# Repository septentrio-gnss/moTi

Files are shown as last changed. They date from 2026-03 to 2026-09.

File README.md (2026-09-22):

# moTi
| Role | Contact |
|---|---|
| Author | [laekaz](https://github.com/laekaz) |
| Maintainer  | [Septentrio GNSS GitHub User](githubuser@septentrio.com) |
| License | [OCP CLA](https://www.opencompute.org/documents/ocp-cla) |
| Project | [Stargate](https://stargate-receiver.com/) |

<p align="center">
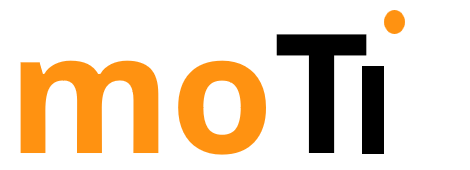
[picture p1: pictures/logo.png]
  
</p>

This project is co-funded by the European Union Agency for the Space Programme under the Fundamental Elements Grant EUSPA/GRANT/02/2024

## Table of Contents
* [Introduction](#introduction)
* [What is a moTi?](#what-is-the-moTi)
  * [Can I buy it?](#can-i-buy-it)
* [What is a Time Card?](#what-is-a-time-card)
* [What is a Mosaic-G5 T?](#what-is-a-mosaic-g5-t)
* [Who is Septentrio?](#who-is-septentrio)
  * [Why open-source?](#why-open-source)
* [Disclaimer](#disclaimer)
* [Deliverables](#deliverables)
  * [M.2 Form Factor](#m2-form-factor)
* [User Documentation](#user-documentation)
  * [System Setup](#system-setup)
    * [Boot Linux](#boot-linux)
    * [Check the GNSS Status (Satellite Time)](#check-the-gnss-status-satellite-time)
    * [Output the PPS and Clock](#output-the-pps-and-clock)
    * [Use the PHC from Linux](#use-the-phc-from-linux)
    * [When the Card is Installed and Running](#when-the-card-is-installed-and-running)
    * [If Something Goes Wrong](#if-something-goes-wrong)
* [Design Documentation](#design-documentation)
  * [Ordering Mosaic](#ordering-mosaic)
  * [Board Connections and Indicators](#board-connections-and-indicators)
    * [Pinout for M.2 Key B Connector](#pinout-for-m2-key-b-connector)
    * [USB 2.0](#usb-20)
    * [UART](#uart)
    * [PPS Out](#pps-out)
    * [Event 1 (PPS IN)](#event-1-pps-in)
    * [LED D1](#led-d1)
    * [Antenna Connector](#antenna-connector)
## Introduction 
## What is a moTi?

<p align="center">
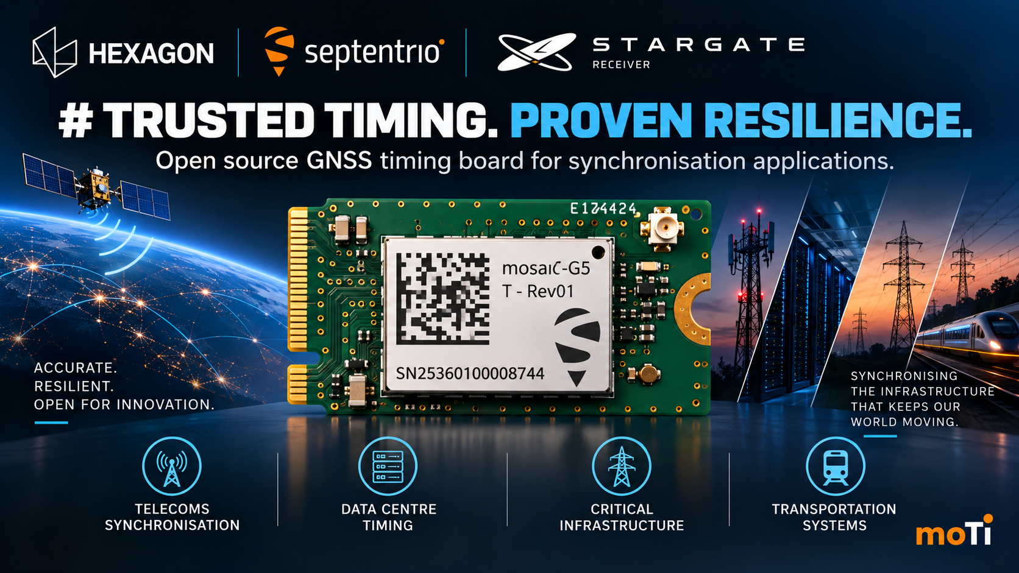
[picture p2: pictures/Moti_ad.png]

</p>

moTi is a timing module that provides accurate and reliable synchronisation signals for time-sensitive systems. It is based on a standardised M.2 form factor that can be easily integrated into compatible carrier boards such as the Open Compute Project (OCP) [Time Card](#what-is-a-Time-Card?).
This board receives precise timing information from Septentrio’s mosaic-G5 T GNSS (Global Navigation Satellite System) module. It then generates synchronisation outputs such as Pulse Per Second (PPS) and Time of Day (ToD) data. These signals are then used to synchronise services, in network interface cards (NICs), and other hardware in data centres and communication systems.

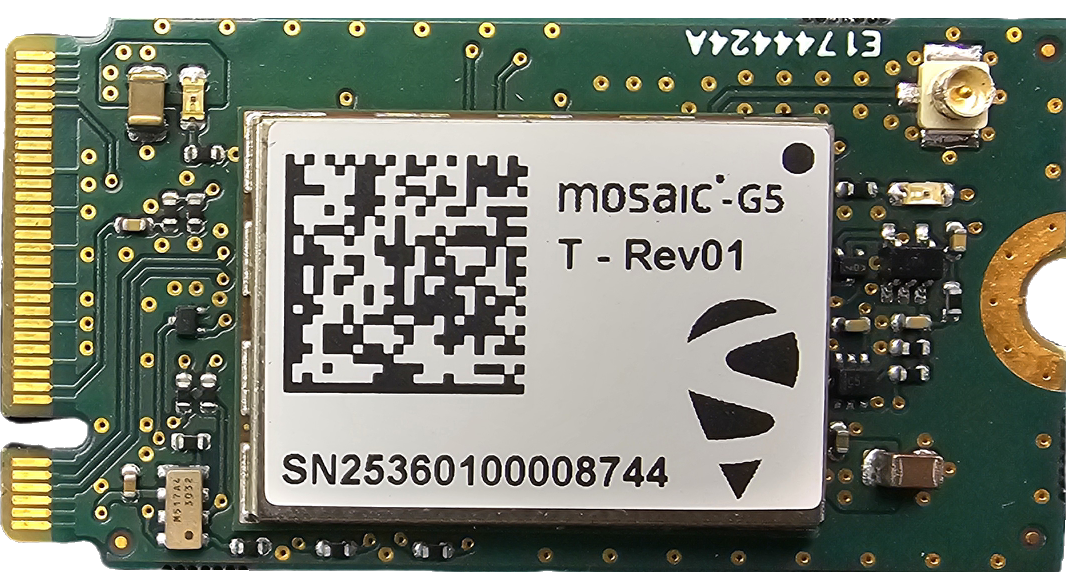
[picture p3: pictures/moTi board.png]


## What is a Time Card?
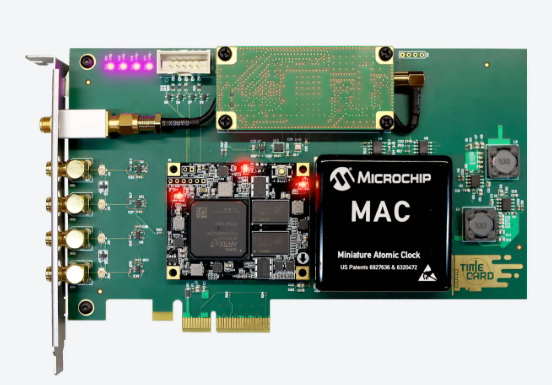
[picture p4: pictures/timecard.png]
card


A Time Card is a PCIe card that is designed to plug into a server and provides precision time outputs such as PPS (Pulse Per Second) and ToD (Time of Day). It provides this precise timing to the server’s clock and network hardware, enabling high-accuracy synchronisation using protocols like the NTP or PTP. moTi connects to the Time Card as a timing source, supplying the card with GNSS time signals in standardised form factor.

Originally, it was developed by Meta and released through the Open Compute Project

More information about the Time Card on this [link](https://fr.scribd.com/document/803083407/M-2-Sync-Module-OCP-Base-Specification-1-1-1) or [Github](https://github.com/Time-Appliances-Project/Time-Card?tab=readme-ov-file) 

## What is a mosaic-G5 T?
[Septentrio mosaic-G5 T](https://www.septentrio.com/en/products/gnss-receivers/gnss-receiver-modules/mosaic-g5-t) is a compact, low-power GNSS timing receiver module with multi-band, multi-frequency capability. Designed for critical infrastructure and other applications where resilient and precise timing is essential, it ensures maximum security and uptime. It tracks all Global Navigation Satellite System (GNSS) constellations and supports both current and future signals. 

## Who is Septentrio?
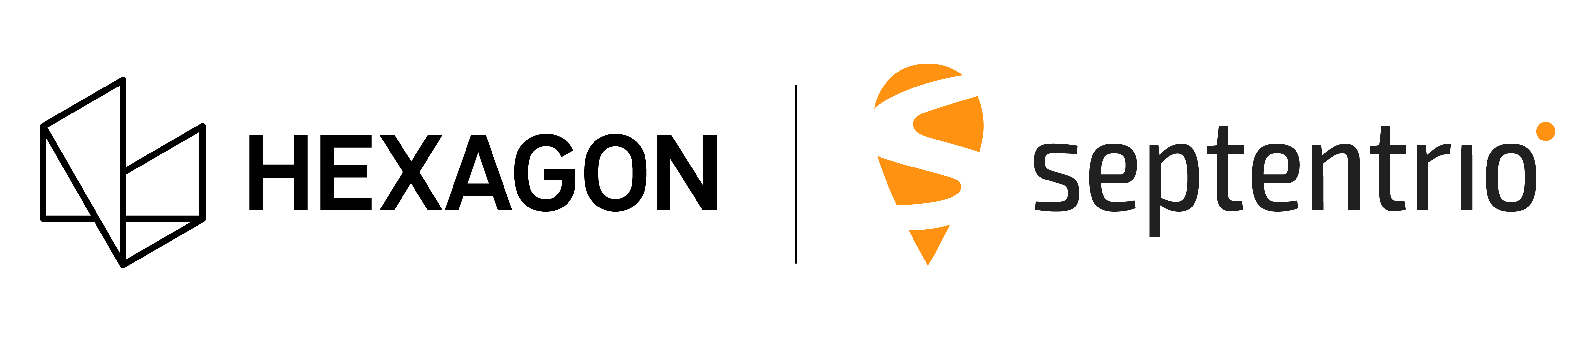
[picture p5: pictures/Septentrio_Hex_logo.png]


Septentrio is a leading company that designs, manufactures and sells high precision and multi-frequency GPS/GNSS receivers for demanding applications. Septentrio products are used in different industries including automotive, marine, construction, rail, machine control, logistics, precision agriculture, geographic information systems (GIS), Unmanned Aerial Vehicles (UAVs), surveying, mapping and scientific development. Septentrio’s receivers constantly deliver accurate and precise GNSS positioning scalable to centimetre-level and designed to perform perfectly in challenging environments. 

Septentrio's technology offers high accuracy and reliability thanks to GNSS + algorithms as well as [Advanced interference Monitoring and Mitigation (AIM+)](https://www.septentrio.com/en/learn-more/advanced-positioning-technology/aim-anti-jamming-protection) This protects your application against jamming (RF interference) and spoofing (malicious attacks).

For more information about Septentrio products go to [**https://www.septentrio.com/**](https://web.septentrio.com/GH-SSN-home).

### Why open-source?
This board is open source to encourage collaboration, customization, and innovation. By making the design files publicly available, developers and engineers can study, modify, and adapt the hardware to fit their specific applications, reducing development time and cost. It also promotes transparency and avoids vendor lock-in, allowing users to fully understand and control the design.

## Disclaimer
This project is offered as-is. The main interfaces have been tested, but the design has not been fully checked or approved by the author or Septentrio. You are responsible for how you use it in your own projects. For guidance on working with Septentrio’s GNSS mosaic modules, we suggest reaching out to Septentrio directly.

Support website: https://www.septentrio.com/en/support

### Deliverables
This open-source project contains the following files for designers, producers and integrators around Septentrio's mosaic modules.
|Files |description |
|---|---|
|[moTi.kicad_pro](./KiCad_Files/KiCad/moTi/moTi.kicad_pro)| KiCAD project|
|[moTi.kicad_sch](./KiCad_Files/KiCad/moTi/moTi.kicad_sch)|KiCAD schematic|
|[mosaic-G5.kicad_sch](./KiCad_Files/KiCad/moTi/mosaic-G5.kicad_sch)|KiCAD mosaic-G5 schematic sheet |
|[M2_Edge connector.kicad_sch](./KiCad_Files/KiCad/moTi/M2_Edge%20connector.kicad_sch)|KiCAD M.2 Key B schematic sheet|
|[Clockdetect.kicad_sch](./KiCad_Files/KiCad/moTi/Clockdetect.kicad_sch)|KiCAD clock schematic sheet|
|[moTi.kicad_pcb](./KiCad_Files/KiCad/moTi/moTi.kicad_pcb)|KiCAD PCB layout|
|[moTi_Schematics.pdf](moTi_Schematics.pdf)|schematic PDF|

#### M.2 form factor

The M.2 form factor provides a compact interface for expansion cards.The moTi board is M.2 Key B connector, but it can also fit into some Key M or B+M slots. B+M slots are designed with extra notches so they accept both Key B and Key M modules, allowing flexibility in installation. This means your Key B board can interconnect with a Key M-compatible slot as long as it’s a B+M slot, ensuring proper electrical connections and compatibility.

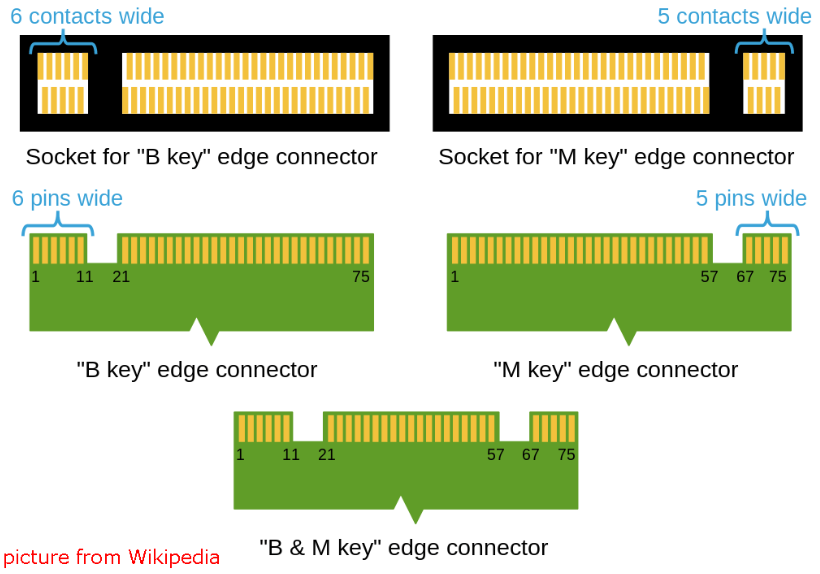
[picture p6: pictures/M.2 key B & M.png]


## User documentation

### System Setup

Before you physically install anything: 
* Make sure you have a free PCIe slot
* Make sure your BIOS supports Virtualization/IOMMU for Linux use
* You must connect the GNSS antenna to its SMA connector before inserting the Time Card.
##### Boot Linux 
Boot Linux with the Time Card inserted. 

If your Linux system uses the Kernel 5.15 or newer the Time Card driver is already included. So the kernel loads the driver automatically.

The devices are exposed by the driver like:

`/dev/ptpX` -> PHC device 

`/dev/ppsY` -> PPS pulse signal

`/sys/class/timecard/ocp0/`-> status and attributes

These are the time interface paths in the OS.

Command example to see the devices:
```
ls -l /sys/class/timecard/ocp0/
```

This will show many devices including GNSS, PPS, PHC clock and atomic clock serial
##### Check the GNSS status (satellite time)
Once Linux has detected the Time Card:

* GNSS time is usually on a serial port like `/dev/ttyS7` or similar.
* You can run `gpsd` or a tool like `cgps` to check the satellite status.

For example:

```
gpsd /dev/ttyS5
```

* To make sure GPS is sending messages, use tio

```
tio -b 115200 /dev/ttyS5
```
* Check if the FPGA time is correct by checking the NMEA

```
tio -b 115200 /dev/ttyS0
```

##### Output the PPS and Clock
available_sma_outputs contains all available outputs

To list available outputs:
```
cat available_sma_outputs
    10MHz PHC MAC GNSS1 GNSS2 IRIG DCF GEN1 GEN2 GEN3 GEN4 GND VCC
```
```
 cat /sys/class/timecard/ocp0/available_sma_outputs 
```
Output on SMA:
* FPGA PPS 
```
echo OUT: PHC >> sma1
```
* Atomic Clock PPS
```
echo OUT: MAC >> sma1
 ```
* GPS Module's PPS 
```
echo OUT: GNSS1 >> sma1
```

##### Use the PHC from Linux
The PHC (Precision Hardware Clock) device exposed by the driver can be used to sync the Linux system clock

##### When the card is installed and running
Once everything is configured:
* The Time Card provides accurate time to Linux
* You can serve time to network clients using NTP or PTP
* Your system becomes a Stratum 1 time source 

This means your server can act as a time source for the whole infrastructure.

##### If something goes wrong
* If the driver fails to load: make sure you have a newer Linux kernel
* If /dev/ptp doesn’t show: check BIOS PCIe settings
* If no GNSS: verify if antenna is connected.

These are normal steps to get the Time Card recognized by Linux.

## Design documentation
#### Ordering mosaic
For orders of the mosaic-G5 T, please contact [Septentrio](https://www.septentrio.com/en/products/gnss-receivers/gnss-receiver-modules/mosaic-g5-t)

### Block diagram
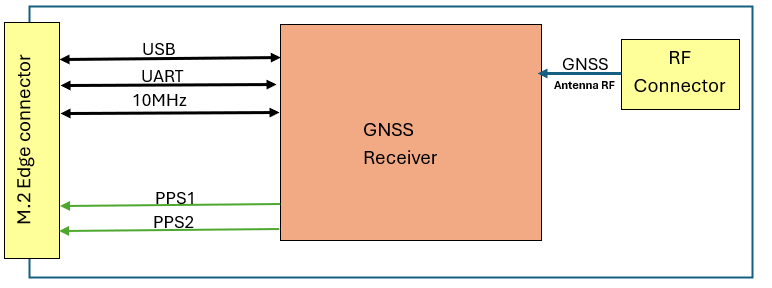
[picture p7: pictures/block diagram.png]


The above block diagram is showing the overview communication between the antenna, receiver and M.2 edge connector. 

### Board connections and indicators

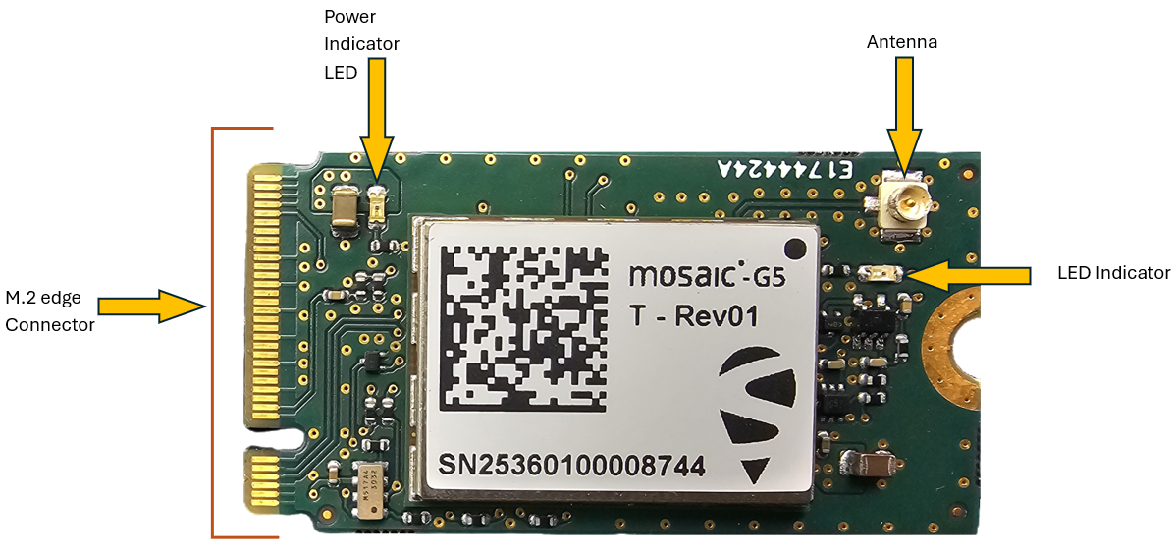
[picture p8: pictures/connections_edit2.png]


| interface signals |I/O Type | Voltage | Signal Description |
|---|---|---|---|
| Power | Power |  3.3V |3.3 V Supply pin. |
| UART | I&O | 3.3V | Universal Asynchronous Receiver Transmitter, RX & TX|
|USB | I/O |  3.3V | Universal Serial Bus interface, USB D+ and D− differential data lines|
| PPS Out 1 | O | 3.3V |Pulse Per Second signal out#1.
| PPS Out 2 | O | 3.3V |Pulse Per Second signal out#2.
| Event 1 (PPS IN)  | I | 3.3V  |Pulse Per Second reference signal input. If not used, connect to ground on Platforms.|
| CLK_IN | I | 3.3V |10MHz reference clock input. If not used, connect to ground|
| CLK_OUT | O | 3.3V |10MHz output clock. |
| LED D1 | O | 3.3V |Power Supply indicator|

#### Pinout for M.2 Key B Connector

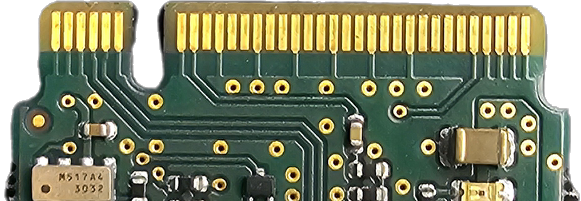
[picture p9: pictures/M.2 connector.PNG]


| Pin # |Signal |
|---|---|
| 7	 |USB D+ |
| 9	 |USB D- |
| 23	|10MHz clock input |
| 67	|nRST_IN |
| 2, 4	|VBAT |
| 10	|LED#1 |
| 20	|PPS2 output |
| 22	|Ref_CLK_SEL |
| 24	|PPS input |
| 46	|PPS1 output |
| 48	|10MHz clock output|
| 62	|UART COM1 Rx |
| 64	|UART COM1 Tx |
| 70, 72, 74| Power 3.3V |
| GND	|GND |

**USB 2.0** pins USB_D+ and USB_D- 
When the module is inserted into a card that supports USB pins on its edge connector, the USB interface works just like it would on any other device. It is used for data, configuration, and control. It carries data such as , Time of Day (ToD) for the GNSS, diagnostic messages and firmware update channels. The Time Card will act as the USB host.

**UART** (Universal Asynchronous Receiver Transmitter)
This is a standard serial port using TX and RX pins.

**PPS Out** timing reference signal output. This supplies high-precision timing references directly into the Time Card clocking system. 

**Event 1 (PPS IN)** This pin detects a pulse from an external device and records the exact GNSS time when the pulse happened. It is connected to the eventB pin of the mosaic-G5 T

##### LED D1
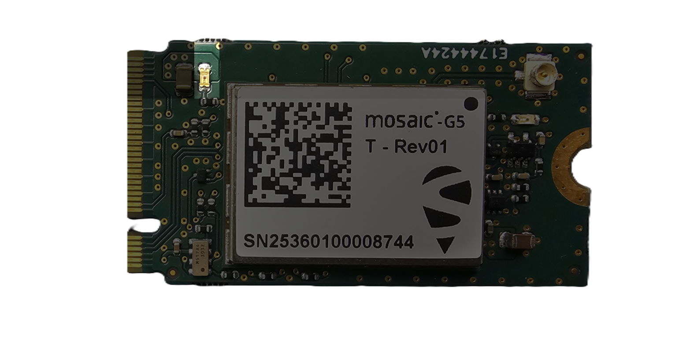
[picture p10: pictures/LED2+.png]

This LED indicates whether the Module is ON/OFF

##### Antenna connector
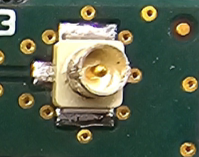
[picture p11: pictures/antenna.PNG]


The board provides a U.FL (UMCC) 50 Ω PCB receptacle for connecting an external GNSS antenna.
This miniature RF connector is commonly used in compact embedded and wireless systems due to its small size and reliable high-frequency performance.

**Connector Details**
* Type: U.FL (UMCC) Receptacle
* Impedance: 50 Ω
* Application: External active/passive GNSS antenna connection

**Notes**
* Use a compatible U.FL/IPX coaxial cable assembly when connecting an antenna.
* Keep RF cable lengths as short as possible to minimize signal loss.
* Ensure the antenna system is properly matched to 50 Ω impedance for optimal RF performance.

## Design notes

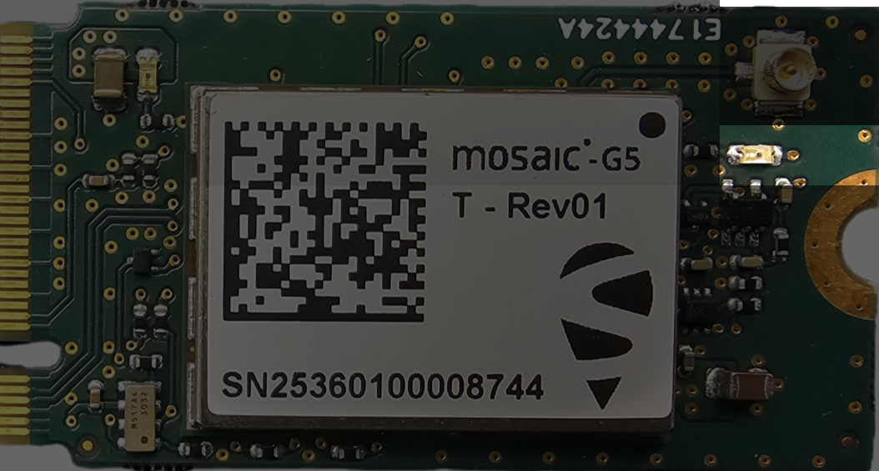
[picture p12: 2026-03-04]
pictures/LED1.PNG

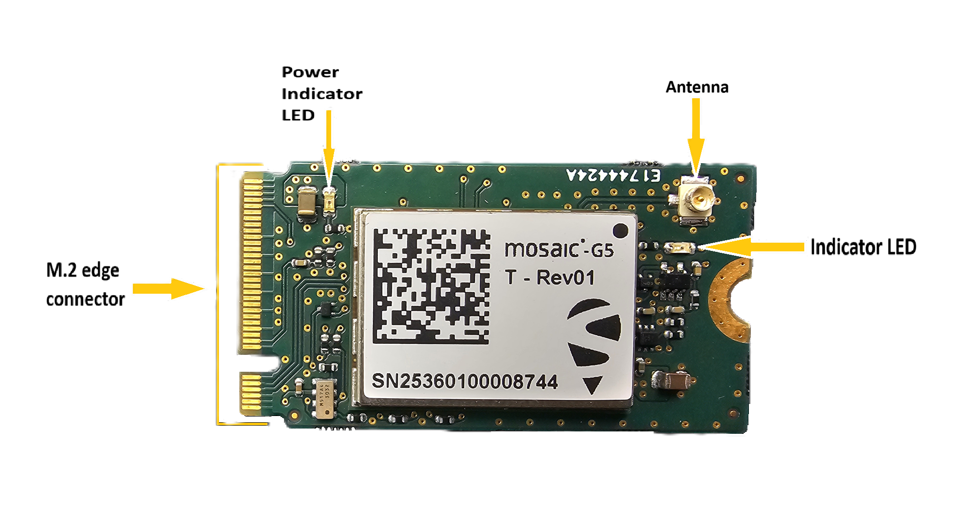
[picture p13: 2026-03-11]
pictures/connections_edit.png

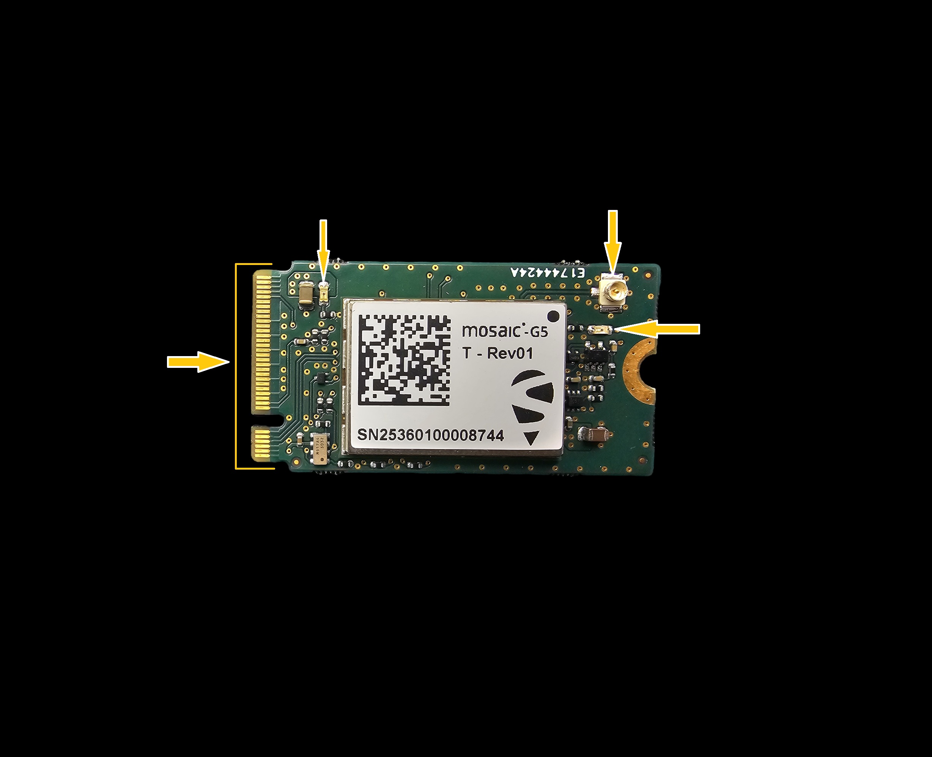
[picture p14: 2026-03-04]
pictures/detailed.jpg

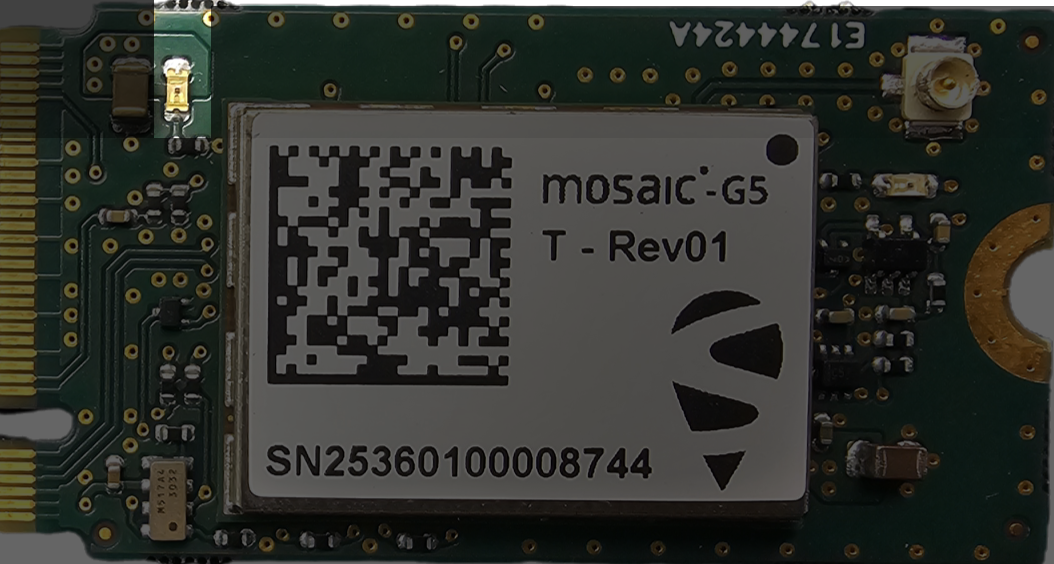
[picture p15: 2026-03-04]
pictures/LED2 .PNG

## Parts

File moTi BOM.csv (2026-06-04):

Reference | Value | Description | Qty | Manufacturer_Name | Manufacturer_Part_Number
C1 | 22u | Unpolarized capacitor | 1 | Murata Electronics | GRM21BC81C226ME44L
C2 | 100n | Unpolarized capacitor | 1 | YAGEO | CC0402KRX7R7BB104
C3 | 47u | CAP CER 47UF 10V X5R 0805 | 1 | Murata Electronics | GRM21BR61A476ME15L
C8 | 1.0n | Unpolarized capacitor | 1 | YAGEO | CC0402KRX7R9BB102
C9 | 1.0n | Unpolarized capacitor | 1 | YAGEO | CC0402KRX7R9BB102
D1 | LED | Light emitting diode | 1 | LITEON | LTST-C191KGKT
D2 | LED | Light emitting diode | 1 | LITEON | LTST-C191KGKT
J1 | U.FL-R-SMT_10_ | U.FL (UMCC) Connector Receptacle, Male Pin 50 Ohms Surface Mount Solder | 1 | Hirose | U.FL-R-SMT(10)
Q1 | NTK3139PT5G | P-channel Switch with Low RDS(on); 44% Smaller Footprint and 38% Thinner than SC-89; Low Threshold Levels, 1.5 V RDS(on) Rating; RoHS Compliant; Operated at Low Logic Level Gate Drive | 1 | onsemi | NTK3139PT5G
Q2 | NTK3043NT1G | Enables High Density PCB Manufacturing; 44% Smaller Footprint than SC-89 and 38% Thinner than SC-89; Low Voltage Drive Makes this Device Ideal for Portable Equipment; Low Threshold Levels, VGS(TH) < 1.3 V; Low Profile (< 0.5 mm) Allows It to Fit Easily in Extremely Thin Environments such as Protable Electronics.; Operated at Standard Logic Level Gate Drive, Facilitating Future Migration to Lower Levels Using the Same Basic Topolgy. | 1 | onsemi | NTK3043NT1G
R1 | 1.0k | Resistor | 1 | Vishay | CRCW04021K00FKEDC
R10 | 10k | Resistor | 1 | Vishay | CRCW040210K0FKED
R11 | 10k | Resistor | 1 | Vishay | CRCW040210K0FKED
R2 | 1.5k | Resistor | 1 | Vishay | CRCW04022K20FKED
R3 | 1.0k | Resistor | 1 | Vishay | CRCW04021K00FKEDC
R4 | 1.0k | Resistor | 1 | Vishay | CRCW04021K00FKEDC
R7 | 10k | Resistor | 1 | Vishay | CRCW040210K0FKED
R8 | 4k7 | Resistor | 1 | Vishay | CRCW04024K70FKED
R9 | 10k | Resistor | 1 | Vishay | CRCW040210K0FKED
U1 | mosaic-G5 T | GNSS timing receiver | 1 | Septentrio | 410504
U2 | TLV3511DCKR | Comparator General Purpose Push-Pull, Rail-to-Rail SC-70-5 ,2.7V ~ 5.5V ,85mA @ 5V ,2.3mV ,-40C ~ 125C ,SC-70-5 | 1 | Texas Instruments | TLV3511DCKR
U5 | SN74LVC1G3157DRLR | Single-Pole, Double-Throw Analog Switch | 1 | Texas Instruments | SN74LVC1G3157DRLR

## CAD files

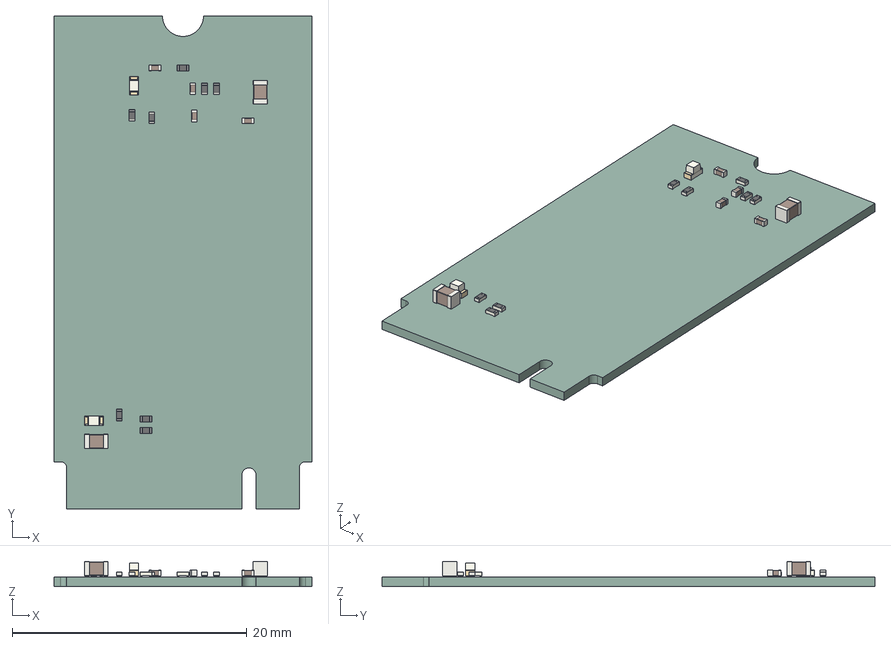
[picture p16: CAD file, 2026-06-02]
KiCad_Files/CAD/moTi.step
22.0 x 42.0 x 2.16 mm
R_0402_1005Metric x 8
C_0402_1005Metric x 4
LED_0603_1608Metric x 2
C_0805_2012Metric x 2
moTi_PCB

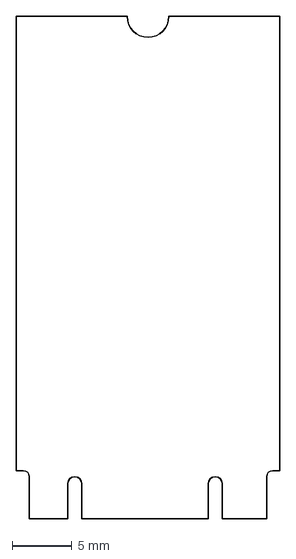
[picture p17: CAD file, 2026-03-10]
KiCad_Files/KiCad/moTi_PCB_OUTLINE.dxf
22.0 x 42.0 mm

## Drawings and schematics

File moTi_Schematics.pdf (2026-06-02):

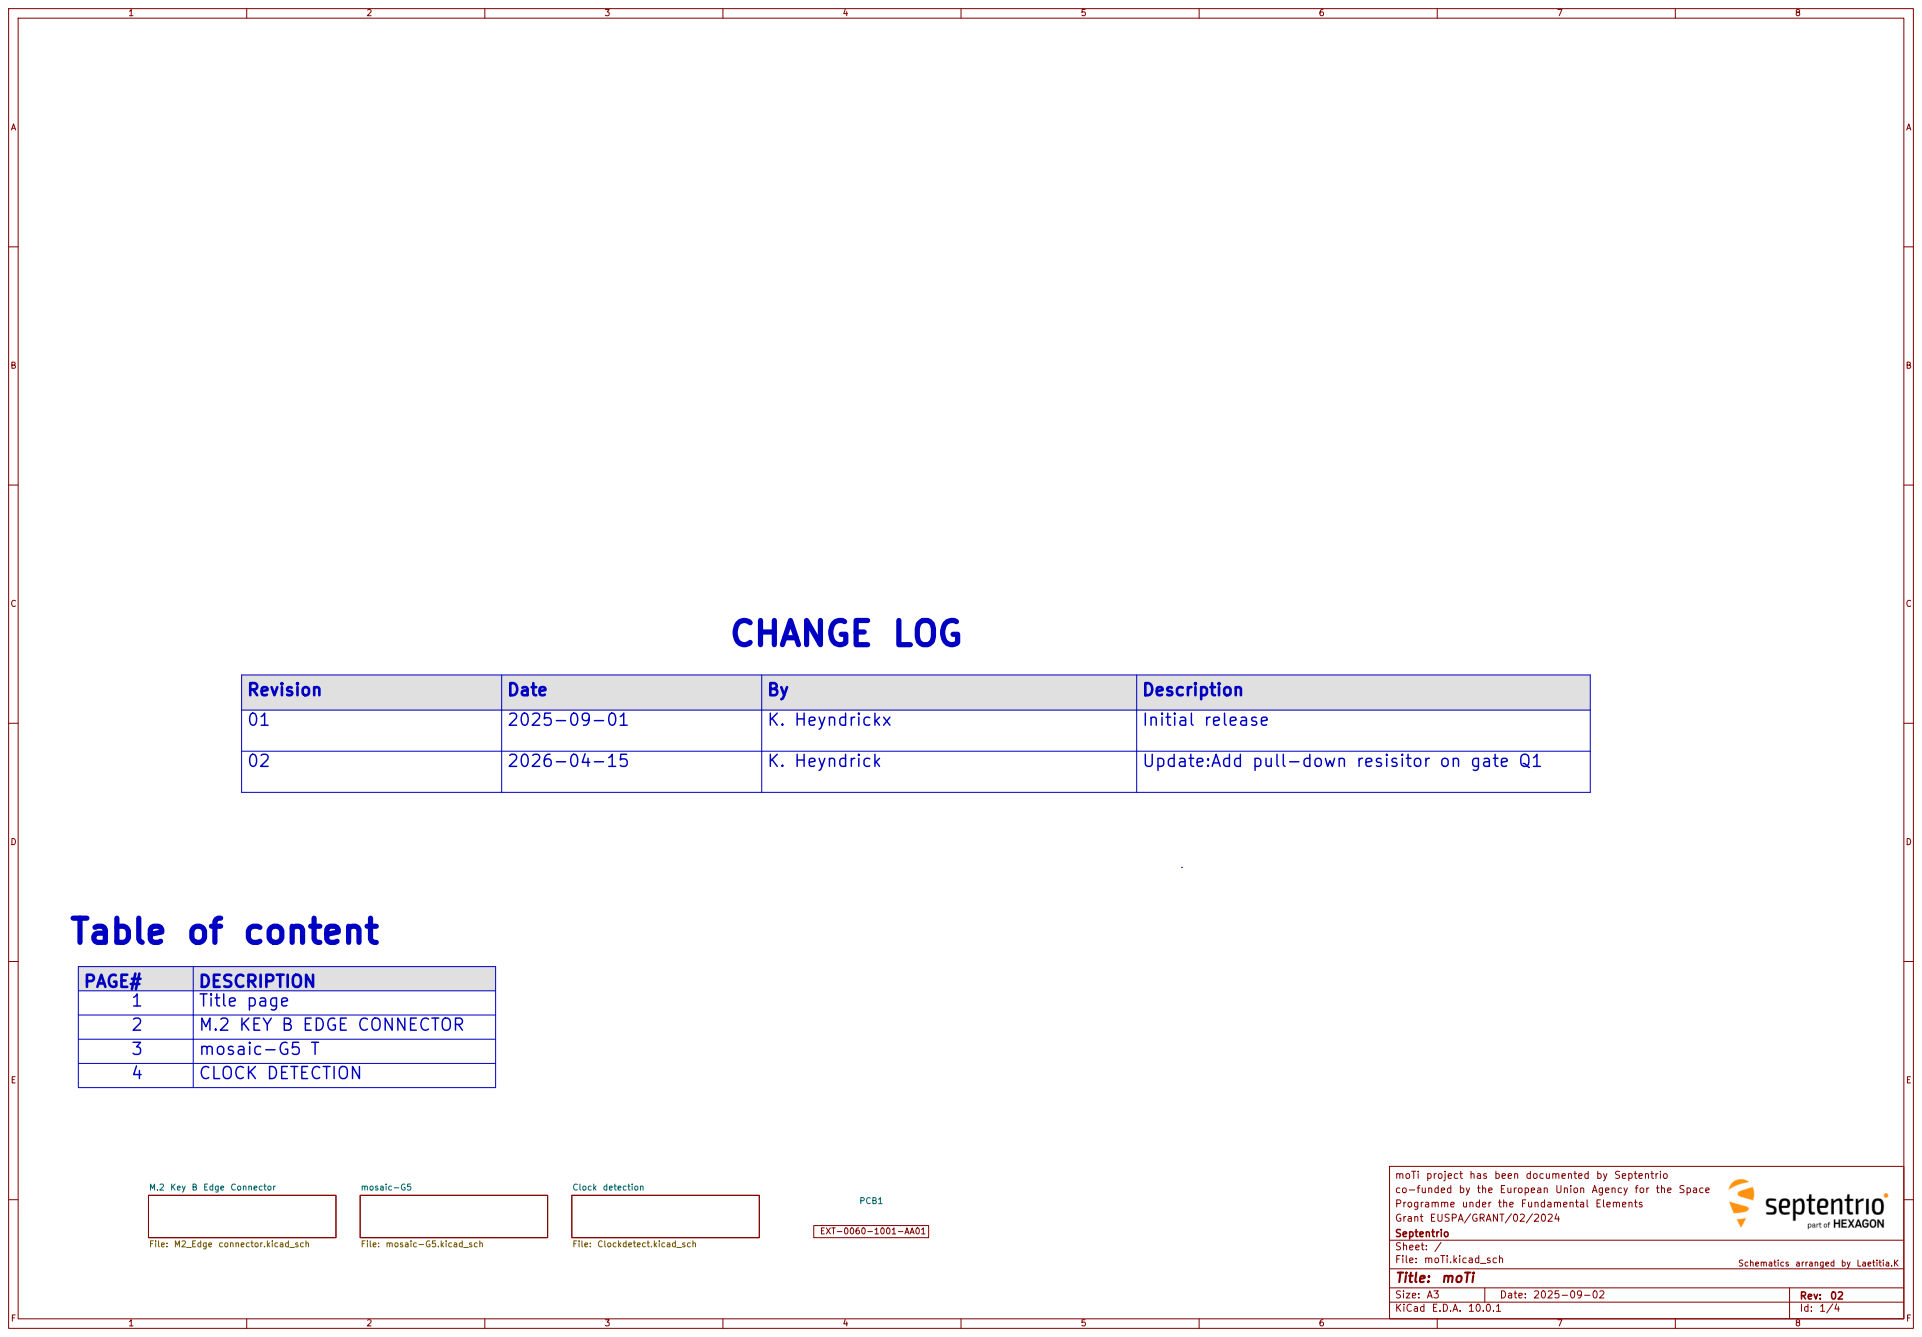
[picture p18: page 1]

Schematics arranged by Laetitia.K CHANGE LOG

01 | 2025-09-01 | K. Heyndrickx | Initial release

02 | 2026-04-15 | K. Heyndrick | Update:Add pull-down resisitor on gate Q1

PAGE# | DESCRIPTION
1 | Title page
2 | M.2 KEY B EDGE CONNECTOR
3 | mosaic-G5 T
4 | CLOCK DETECTION

moTi project has been documented by Septentrio
co-funded by the European Union Agency for the Space
Programme under the Fundamental Elements
Grant EUSPA/GRANT/02/2024
Septentrio
Sheet: /
File: moTi.kicad_sch
Title: moTi

Size: A3 | Rev: 02 | F Date: 2025-09-02
KiCad E.D.A. 10.0.1 | Id: 1/4

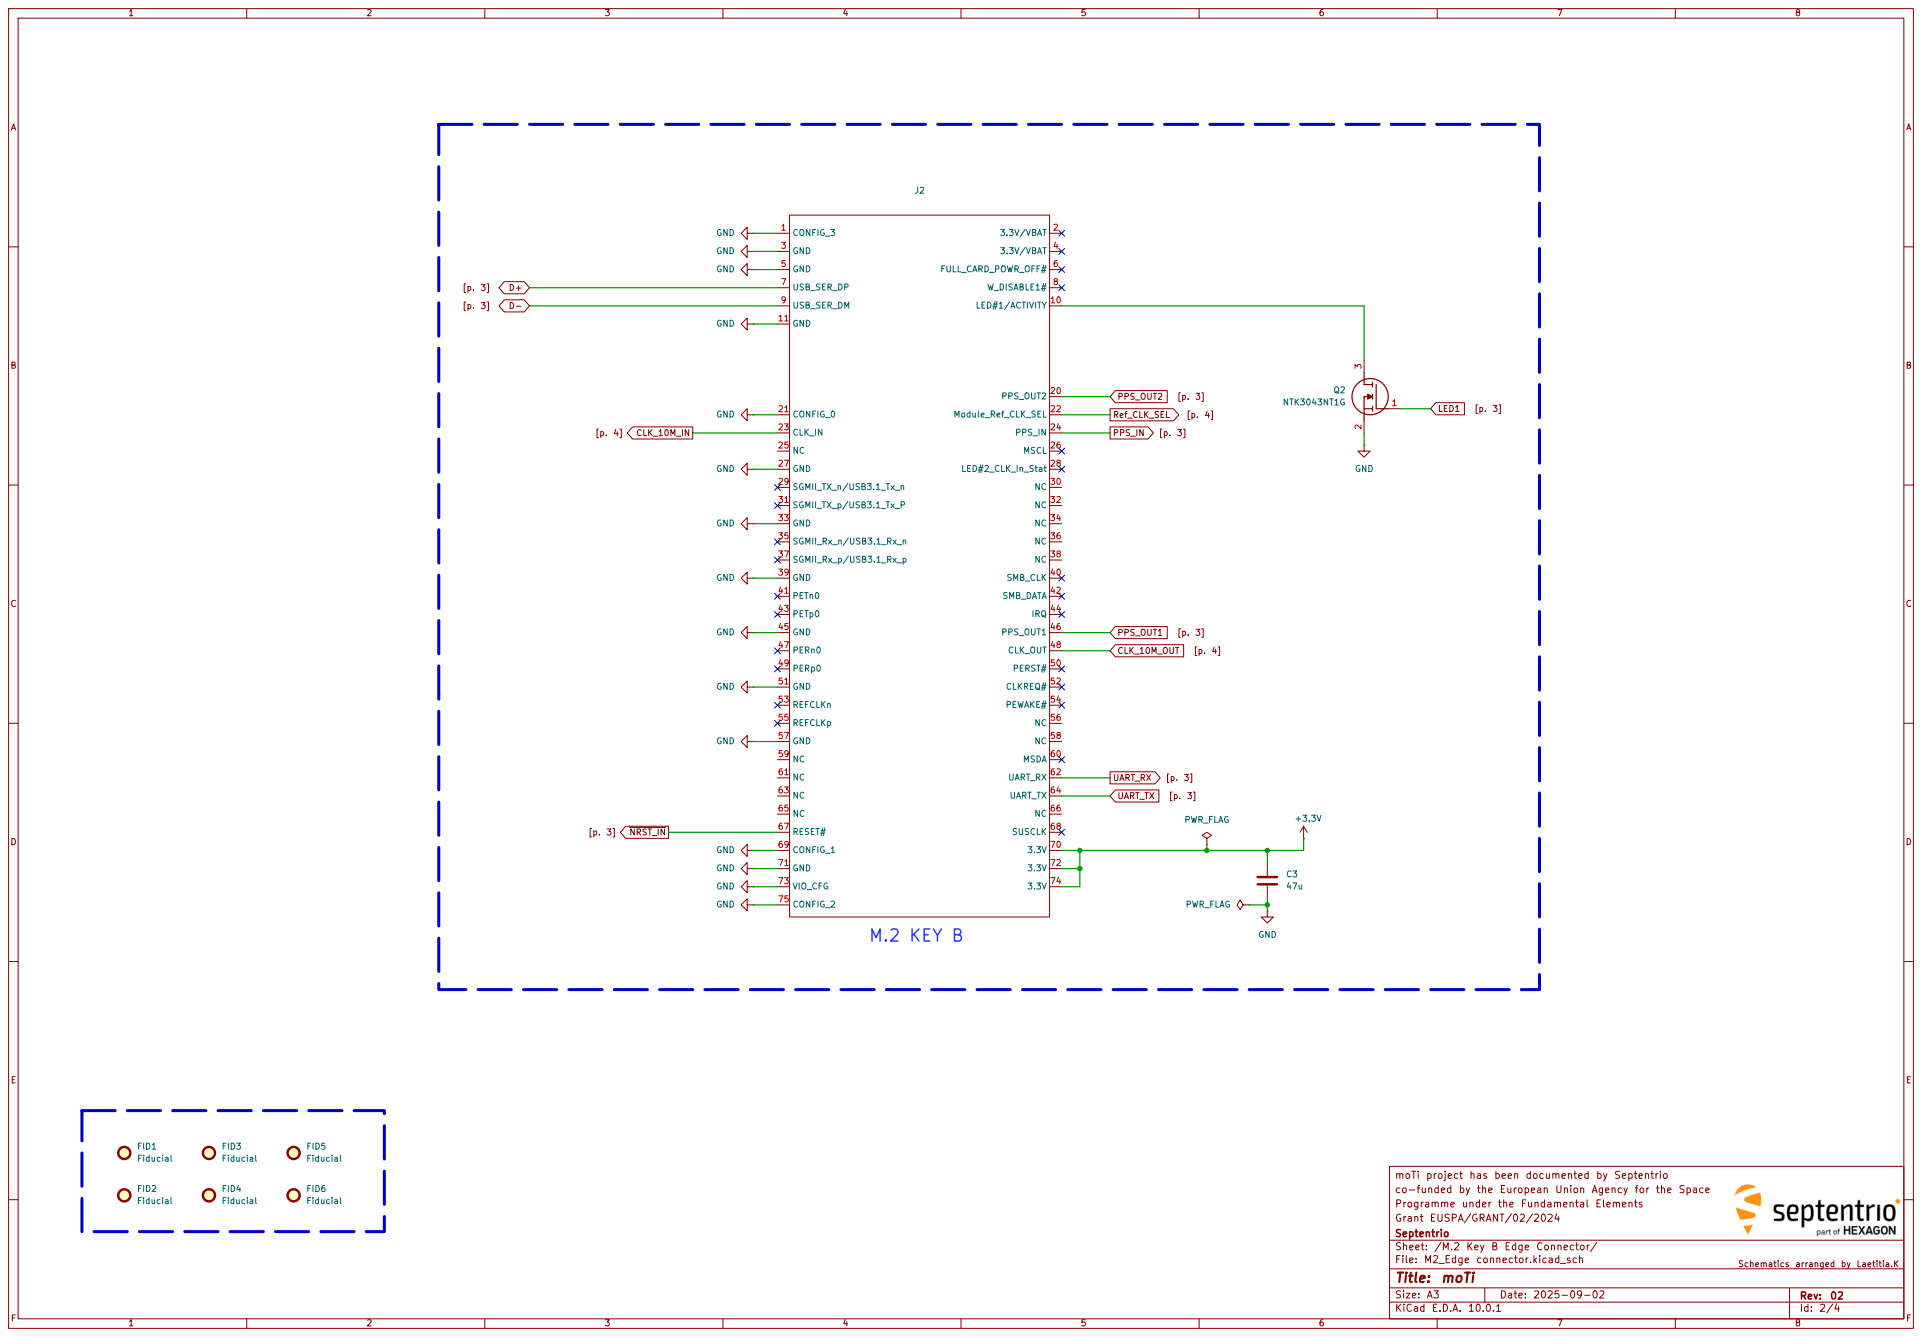
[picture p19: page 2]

moTi project has been documented by Septentrio
co-funded by the European Union Agency for the Space
Programme under the Fundamental Elements
Grant EUSPA/GRANT/02/2024
Septentrio
Sheet: /M.2 Key B Edge Connector/
File: M2_Edge connector.kicad_sch

Schematics arranged by Laetitia.K

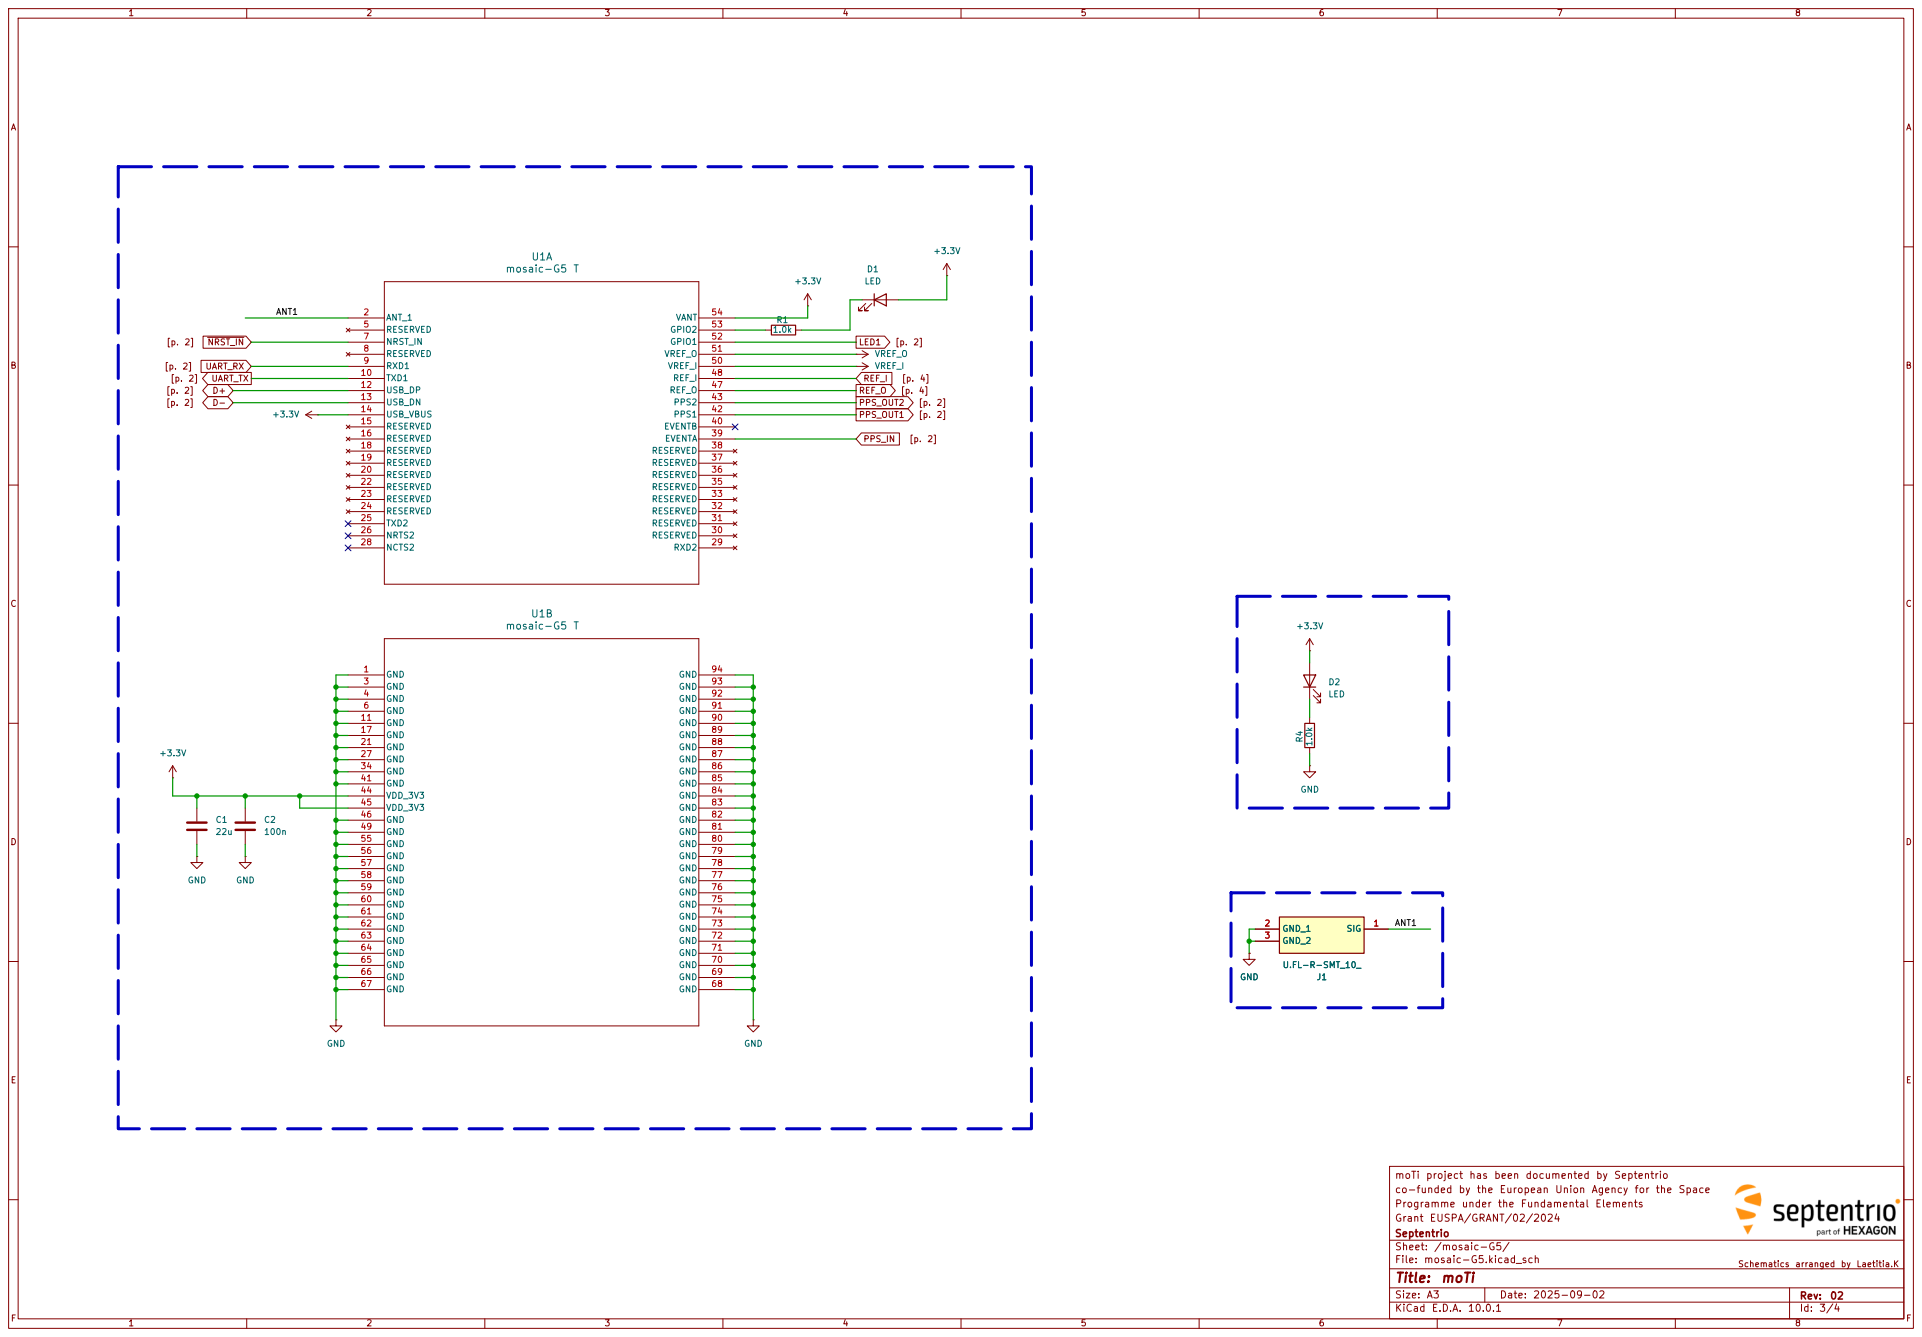
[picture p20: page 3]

moTi project has been documented by Septentrio
co-funded by the European Union Agency for the Space
Programme under the Fundamental Elements
Grant EUSPA/GRANT/02/2024
Septentrio
Sheet: /mosaic-G5/
File: mosaic-G5.kicad_sch

Schematics arranged by Laetitia.K

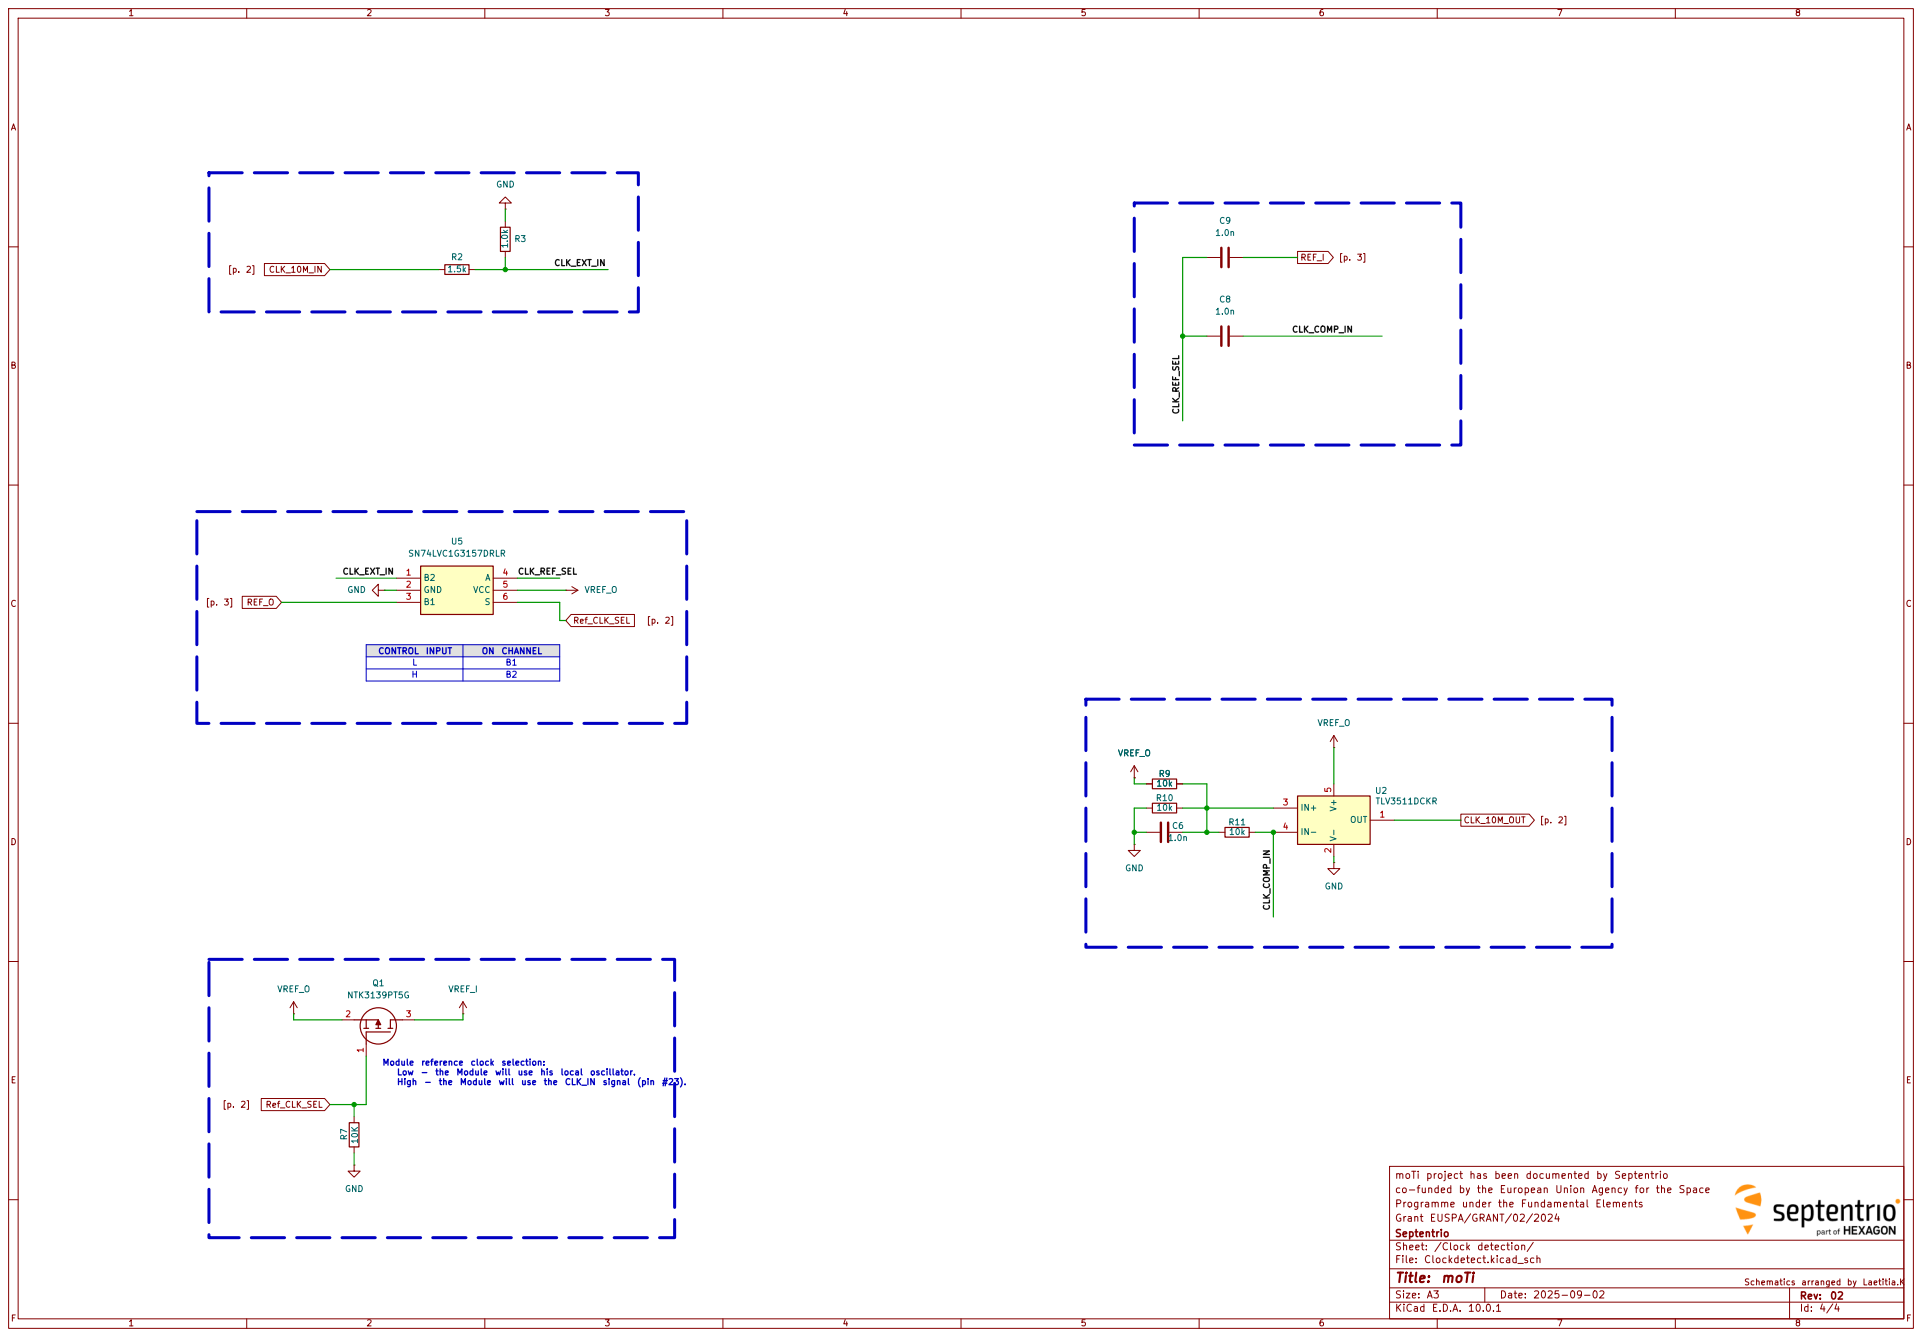
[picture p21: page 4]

CONTROL INPUT | ON CHANNEL

moTi project has been documented by Septentrio
co-funded by the European Union Agency for the Space
Programme under the Fundamental Elements
Grant EUSPA/GRANT/02/2024
Septentrio
Sheet: /Clock detection/
File: Clockdetect.kicad_sch

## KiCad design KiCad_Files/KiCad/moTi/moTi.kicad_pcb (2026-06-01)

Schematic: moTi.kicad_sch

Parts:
PCB1: PCB_label

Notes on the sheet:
Project: moTi Varient: mosaic-G5 T
CHANGE LOG
mosaic-G5 T
Ultra-compact high-precision GNSS time synchronization receiver
Table of content
M.2 Key B with Mosaic G5 GNSS Module
Schematics arranged by Laetitia.K

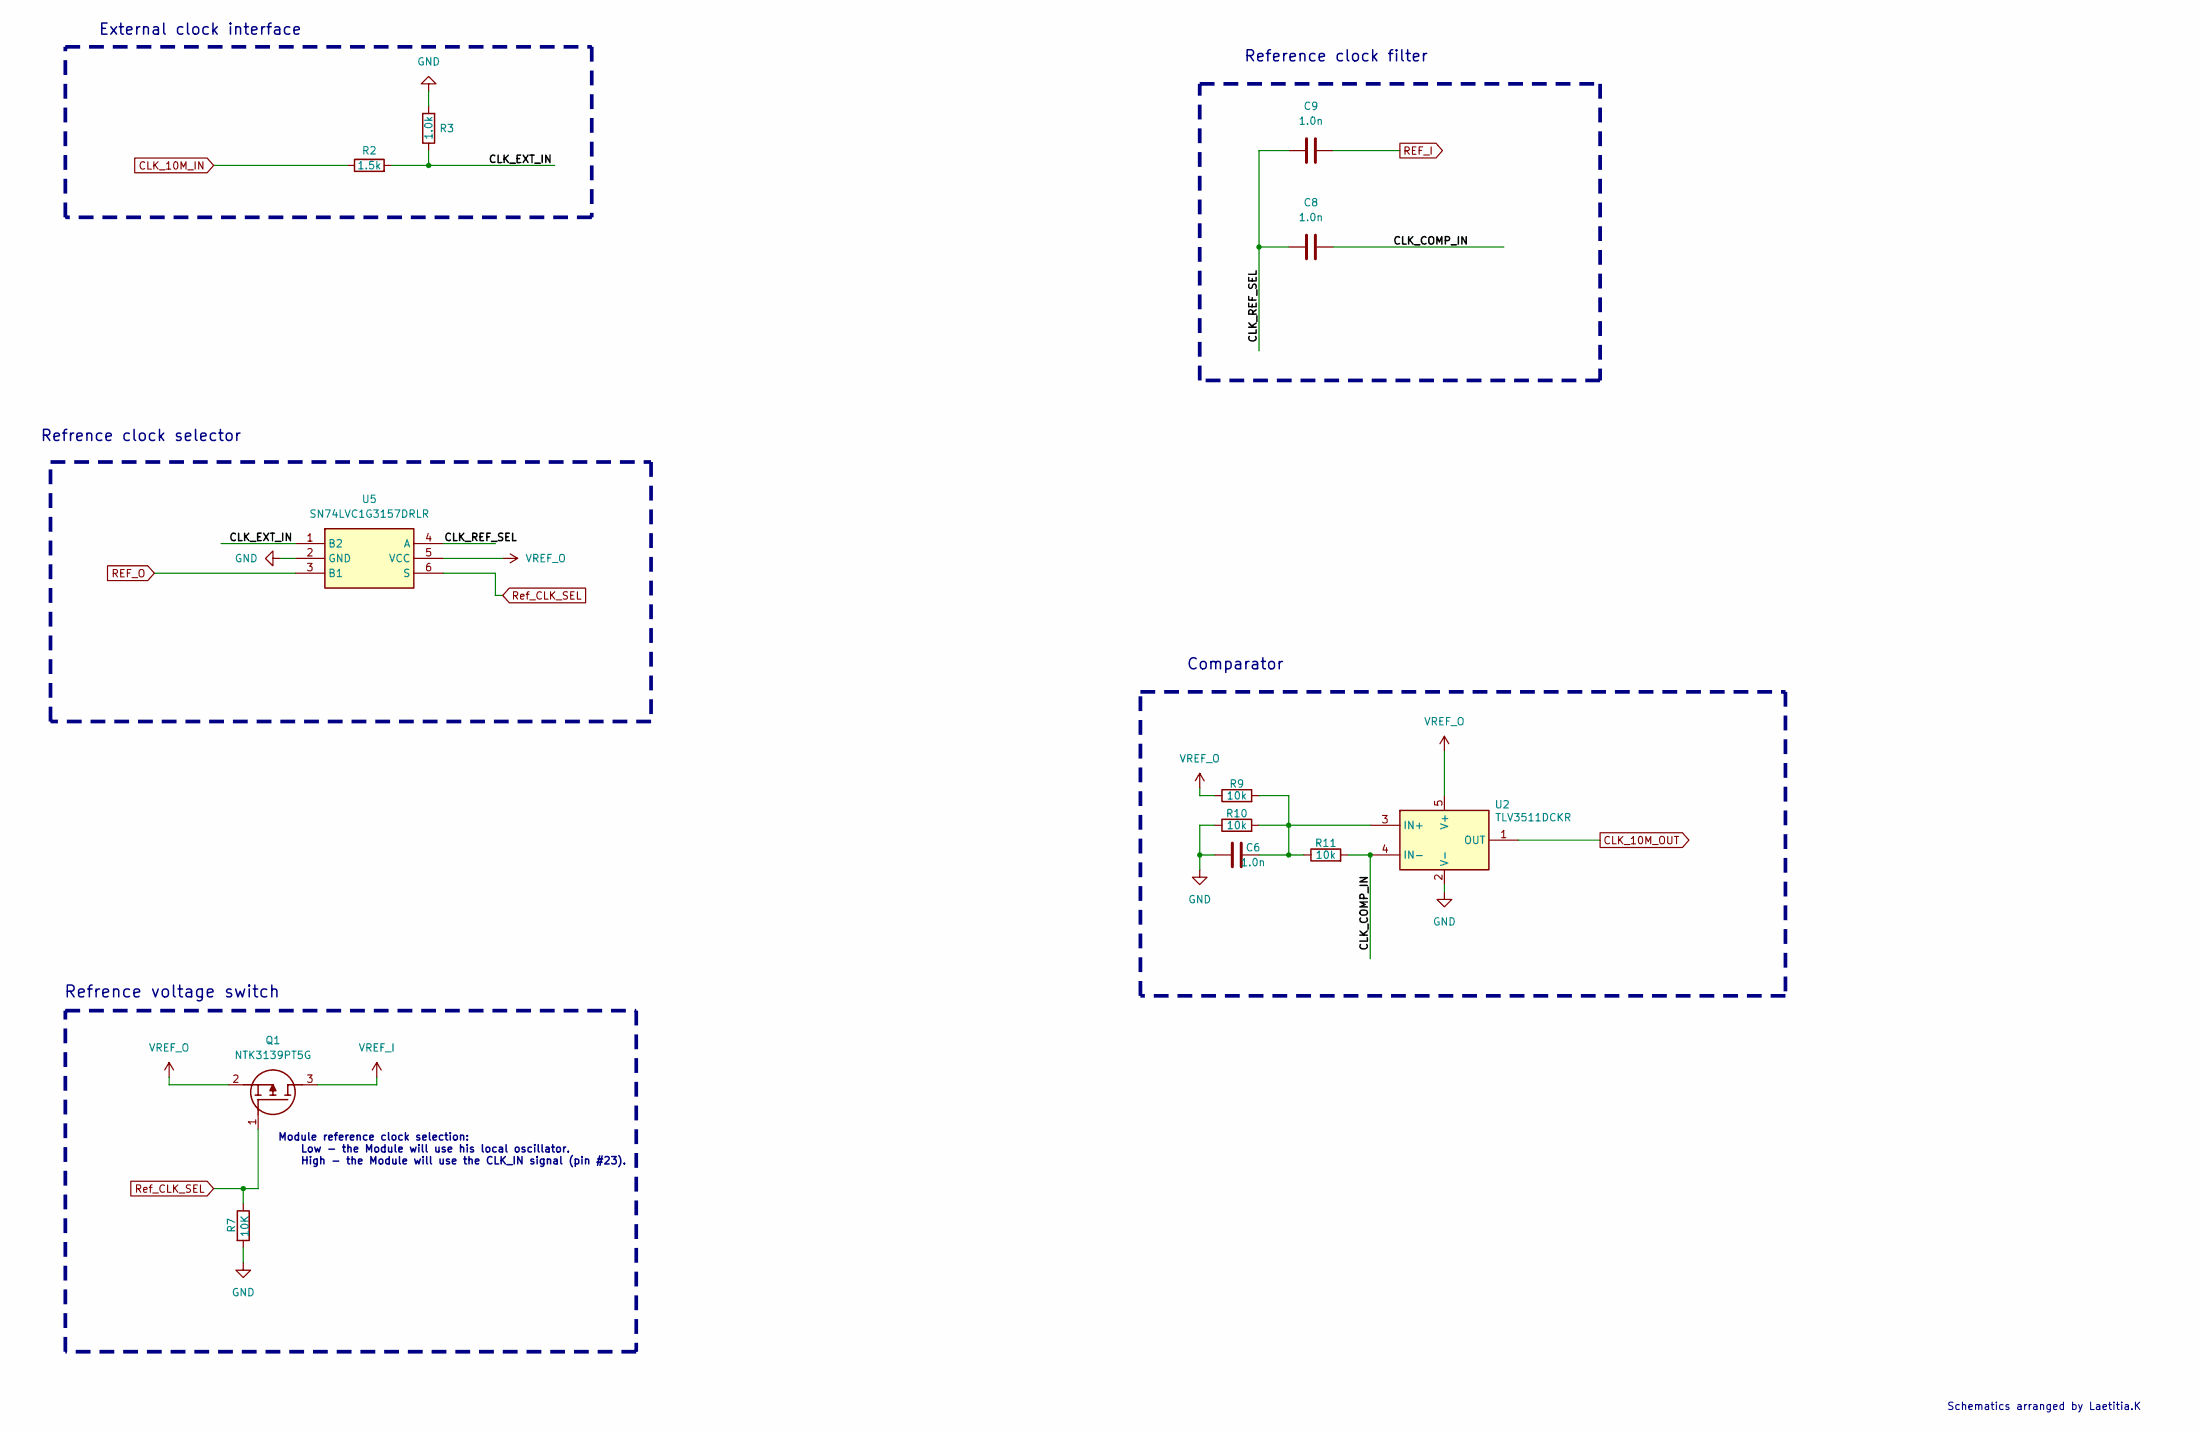
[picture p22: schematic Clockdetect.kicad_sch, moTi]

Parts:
C6, C8, C9: 1.0n; C_0402_1005Metric; Manufacturer_Part_Number CC0402KRX7R9BB102
Q1: NTK3139PT5G; SOTFL40P120X55-3N; Manufacturer_Part_Number NTK3139PT5G; Mouser Part Number 863-NTK3139PT5G
R2: 1.5k; R_0402_1005Metric; Manufacturer_Part_Number CRCW04022K20FKED
R3: 1.0k; R_0402_1005Metric; Manufacturer_Part_Number CRCW04021K00FKEDC
R7: 10K
R9, R10, R11: 10k; R_0402_1005Metric; Manufacturer_Part_Number CRCW040210K0FKED
U2: TLV3511DCKR; SOT65P210X110-5N; Manufacturer_Part_Number TLV3511DCKR
U5: SN74LVC1G3157DRLR; SOTFL50P160X60-6N; Mouser Part Number 595-SN74LVC1G3157DRL

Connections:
CLK_10M_IN: R2.1; also elsewhere on the board
CLK_10M_OUT: U2.1 (OUT); also elsewhere on the board
unnamed: C6.2, R9.2, R10.2, R11.1, U2.3 (IN+)
unnamed: C8.2, R11.2, U2.4 (IN-)
unnamed: C8.1, C9.1, U5.4 (A)
unnamed: R2.2, R3.1, U5.1 (B2)
REF_I: C9.2; also elsewhere on the board
REF_O: U5.3 (B1); also elsewhere on the board
VREF_I: Q1.3 (D); also elsewhere on the board
VREF_O: Q1.2 (S), R9.1, U2.5 (V+), U5.5 (VCC); also elsewhere on the board

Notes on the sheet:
Comparator
External clock interface
Reference clock filter
Refrence clock selector
Refrence voltage switch
Module reference clock selection: Low - the Module will use his local oscillator. High - the Module will use the CLK_IN signal (pin #23).
Schematics arranged by Laetitia.K

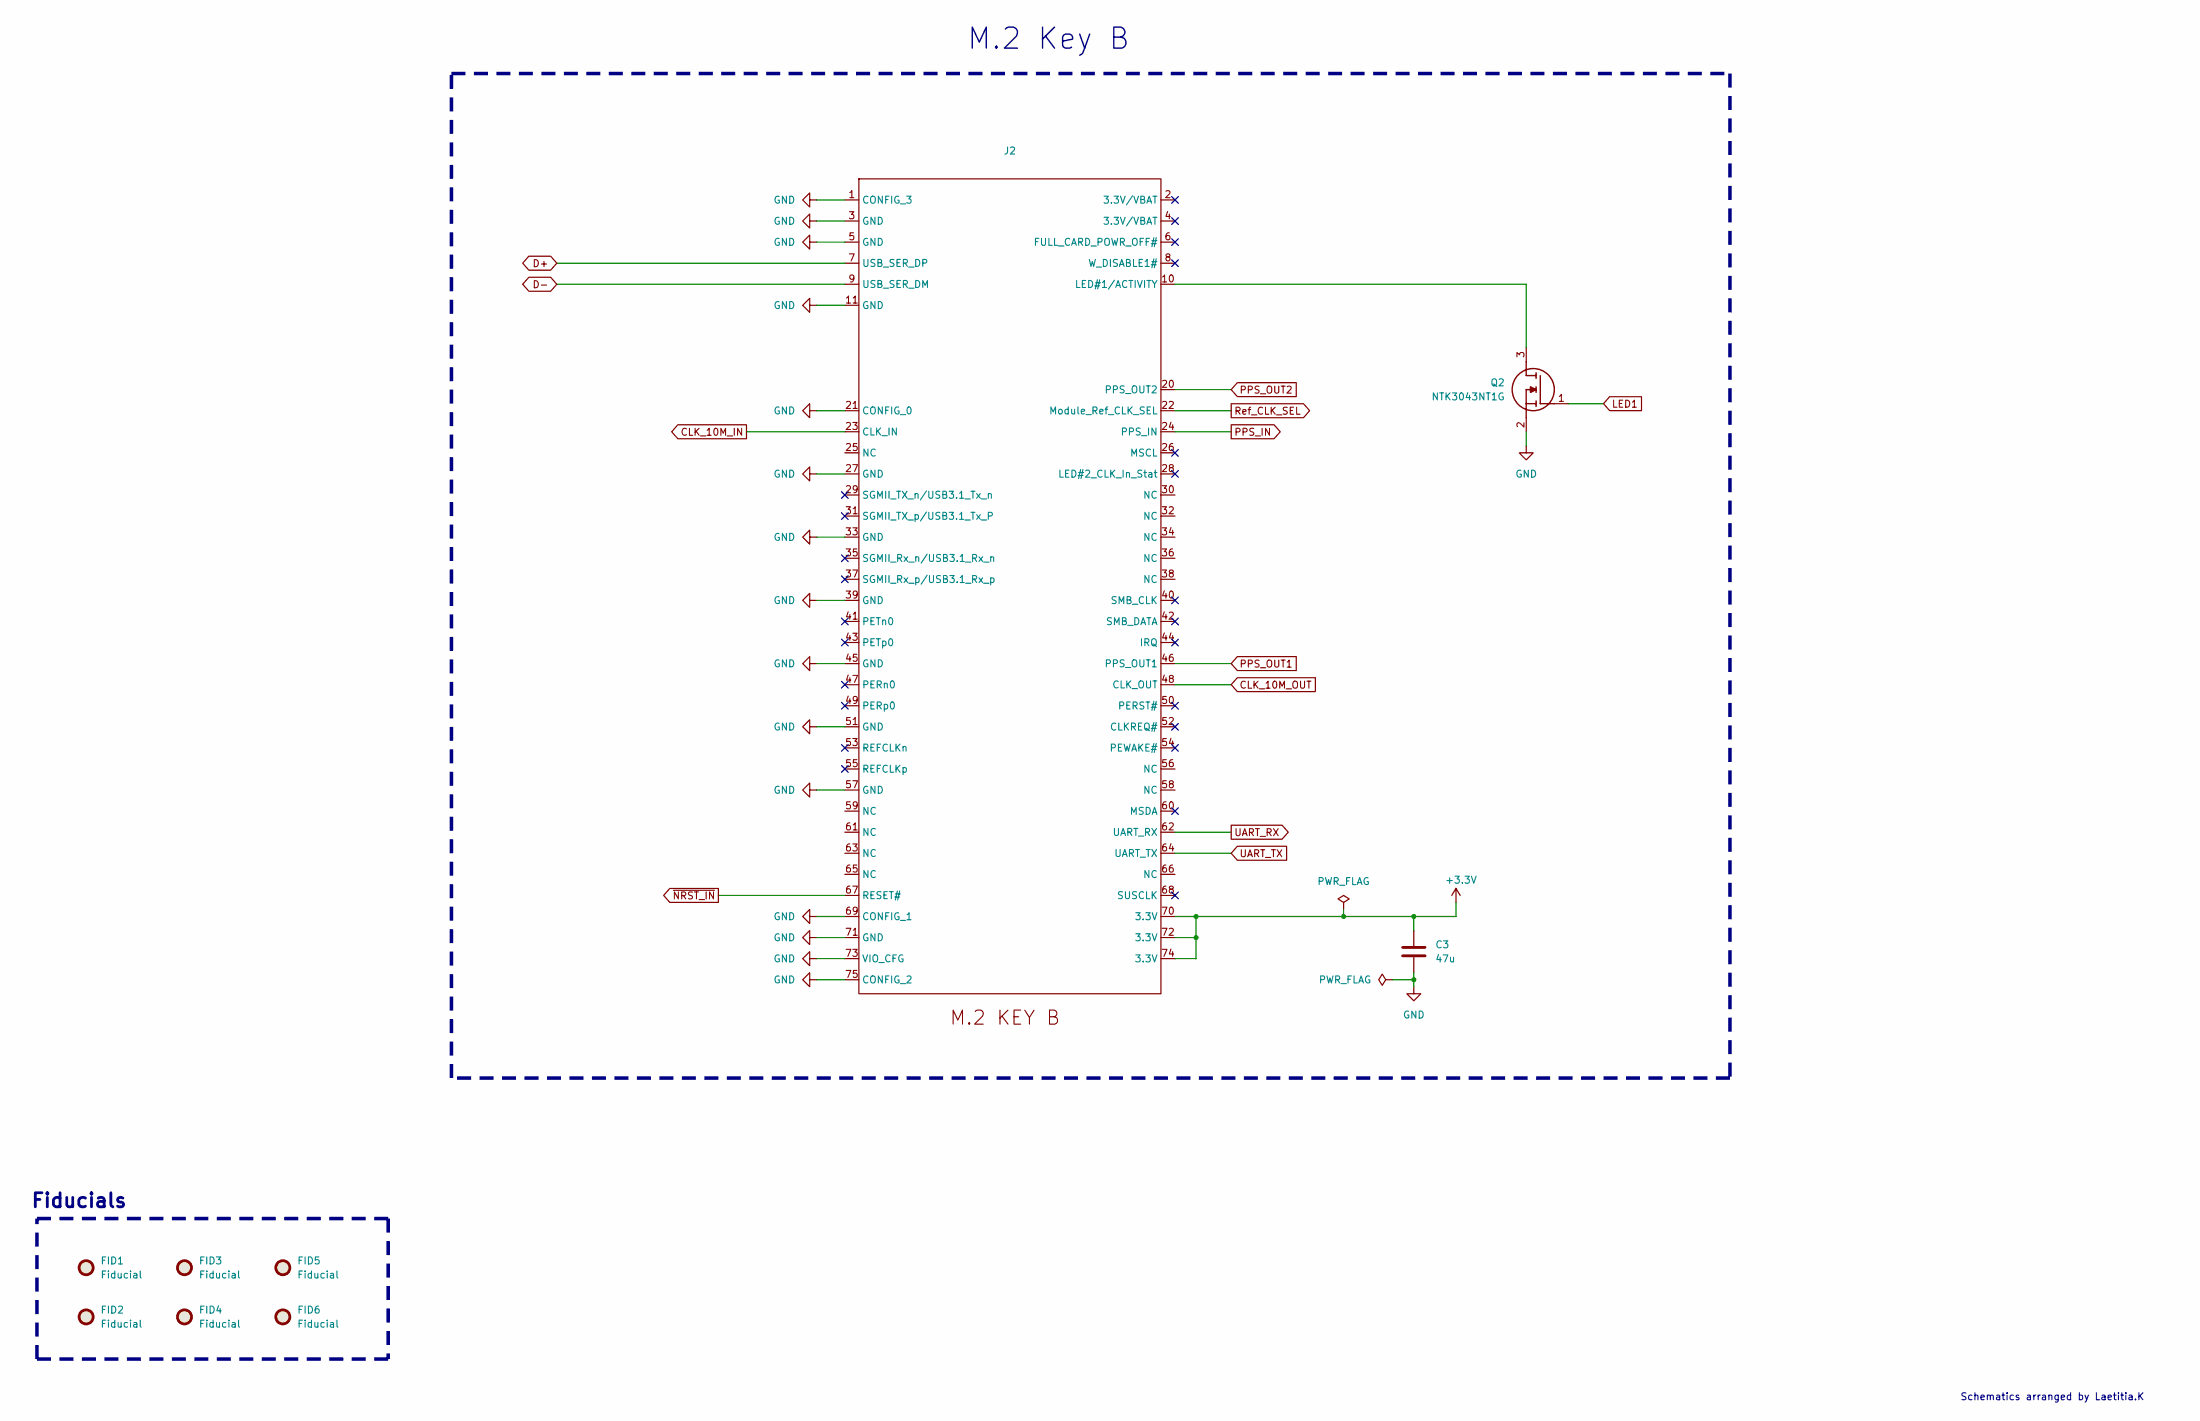
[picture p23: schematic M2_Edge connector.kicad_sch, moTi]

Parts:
C3: 47u; C_0805_2012Metric; Manufacturer_Part_Number GRM21BR61A476ME15L
FID1, FID2, FID3, FID4, FID5, FID6: Fiducial; Fiducial_0.5mm_Mask1mm
J2: NGFF_B
Q2: NTK3043NT1G; MMBT2907AM3T5G; Mouser Part Number 863-NTK3043NT1G

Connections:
+3.3V: C3.1, J2.70 (3.3V), J2.72 (3.3V), J2.74 (3.3V); also elsewhere on the board
CLK_10M_IN: J2.23 (CLK_IN); also elsewhere on the board
CLK_10M_OUT: J2.48 (CLK_OUT); also elsewhere on the board
D+: J2.7 (USB_SER_DP); also elsewhere on the board
D-: J2.9 (USB_SER_DM); also elsewhere on the board
LED1: Q2.1 (G); also elsewhere on the board
unnamed: J2.10 (LED#1/ACTIVITY), Q2.3 (D)
PPS_IN: J2.24 (PPS_IN); also elsewhere on the board
PPS_OUT1: J2.46 (PPS_OUT1); also elsewhere on the board
PPS_OUT2: J2.20 (PPS_OUT2); also elsewhere on the board
UART_RX: J2.62 (UART_RX); also elsewhere on the board
UART_TX: J2.64 (UART_TX); also elsewhere on the board
~NRST_IN: J2.67 (RESET#); also elsewhere on the board

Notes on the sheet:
M.2 Key B
Fiducials
Schematics arranged by Laetitia.K

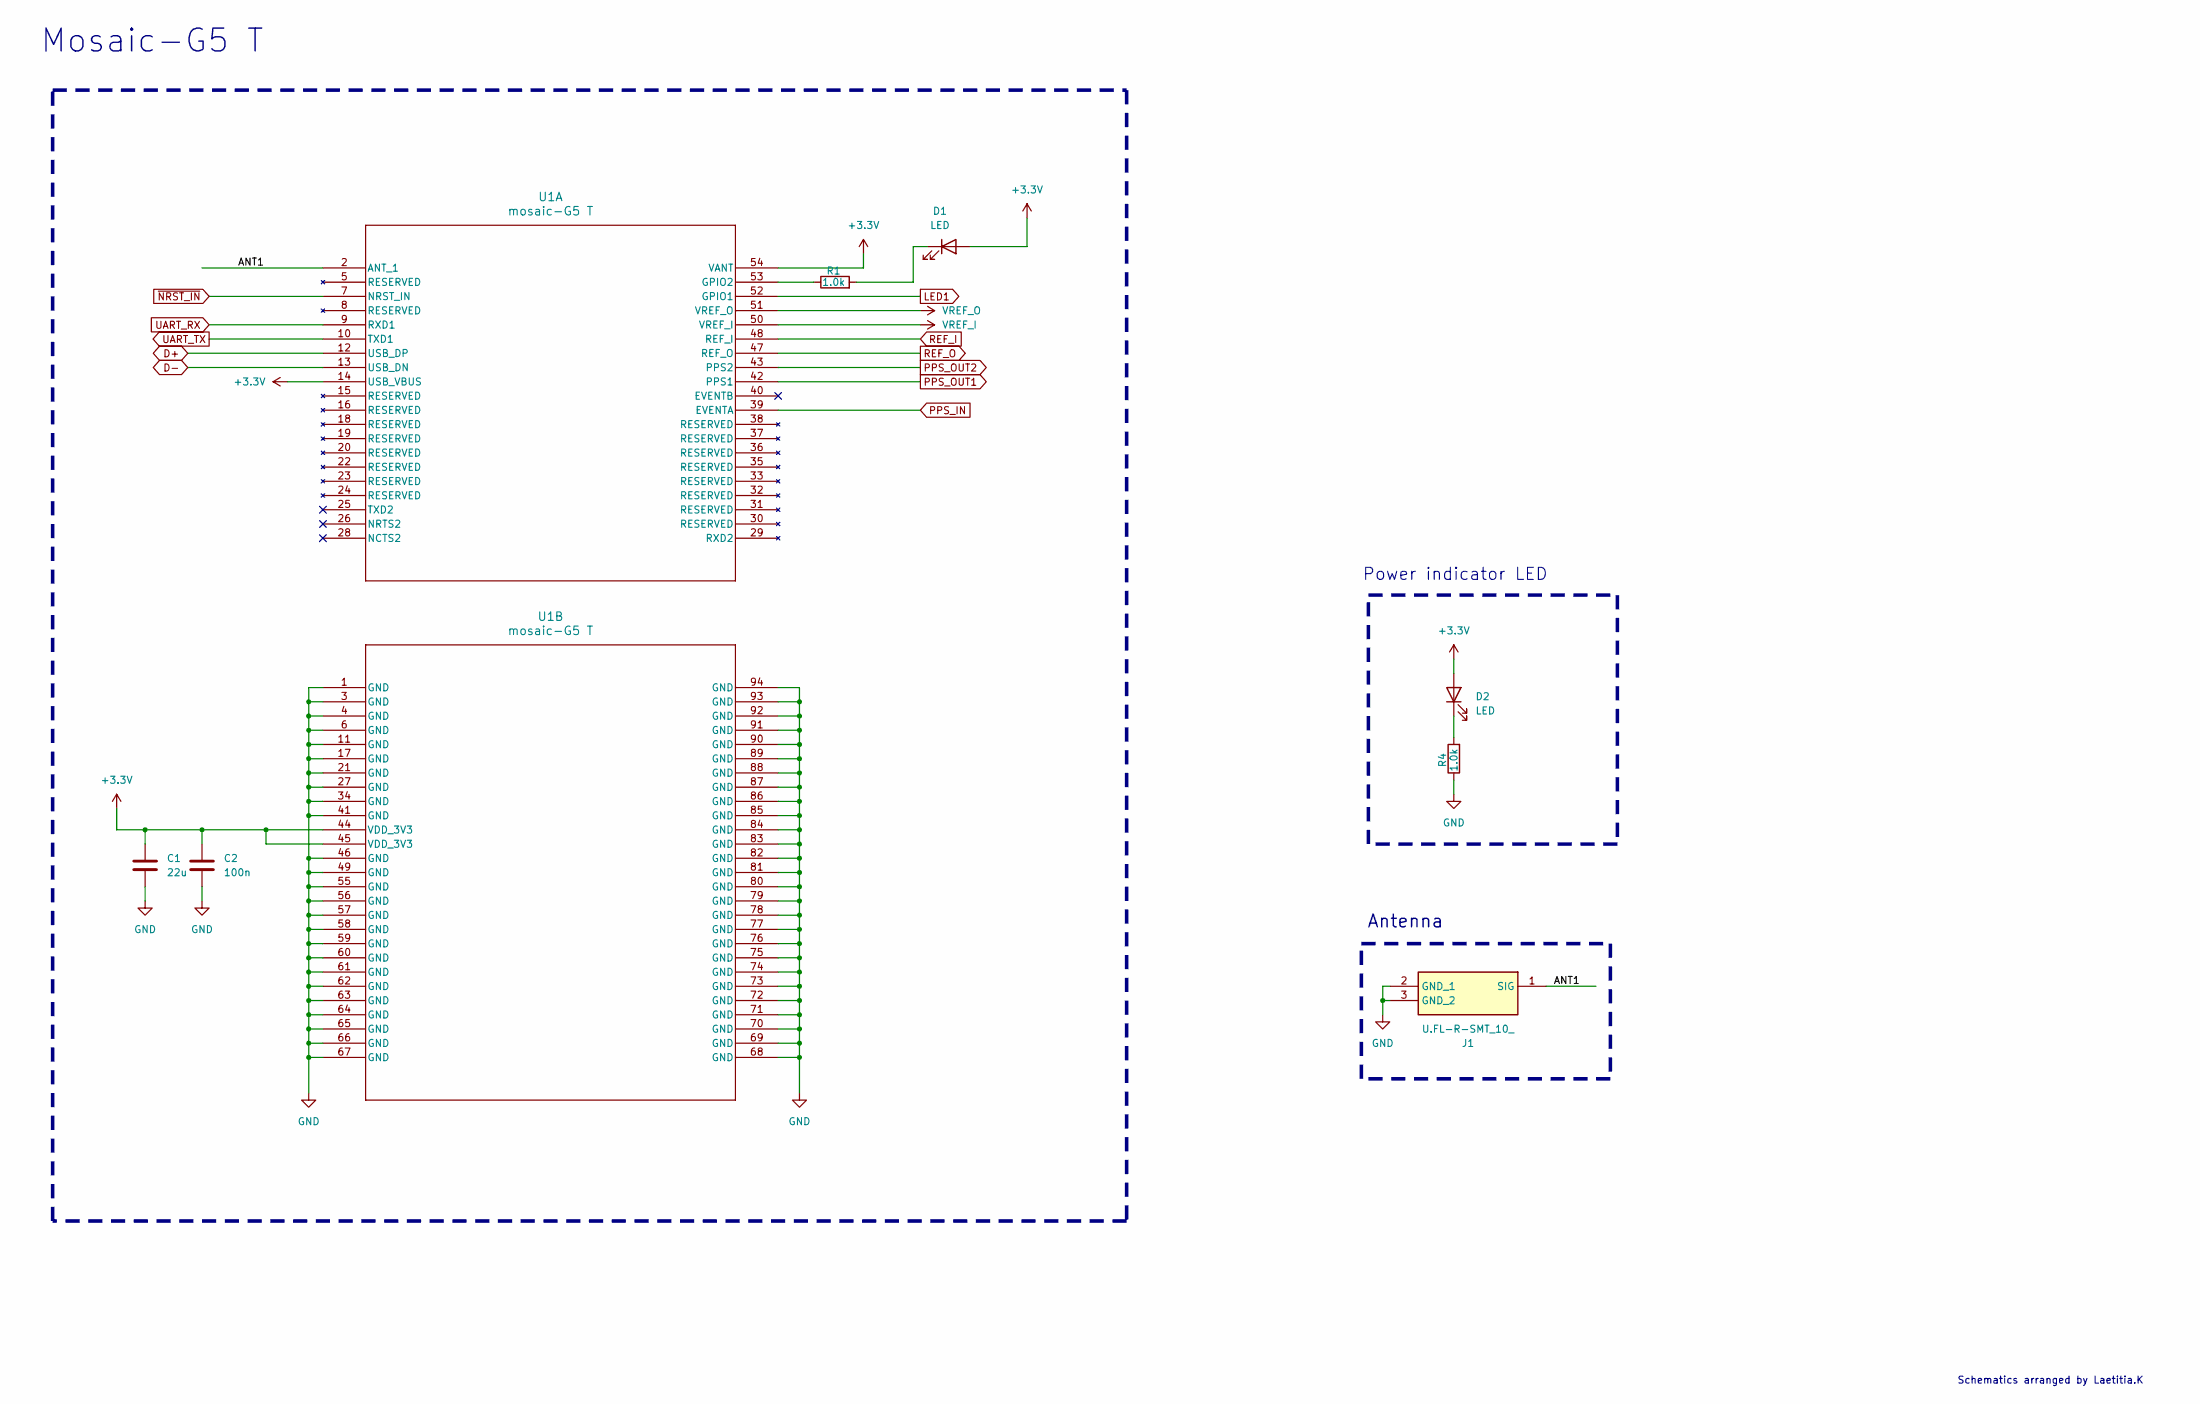
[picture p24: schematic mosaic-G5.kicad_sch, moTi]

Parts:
C1: 22u; C_0805_2012Metric; Manufacturer_Part_Number GRM21BC81C226ME44L
C2: 100n; C_0402_1005Metric; Manufacturer_Part_Number CC0402KRX7R7BB104
D1, D2: LED; LED_0603_1608Metric; Manufacturer_Part_Number LTST-C191KGKT
J1: U.FL-R-SMT_10_; UFLRSMT10; Mouser Part Number 798-U.FL-R-SMT10
R1, R4: 1.0k; R_0402_1005Metric; Manufacturer_Part_Number CRCW04021K00FKEDC
U1: mosaic-G5 T; LGA54_MOSAIC-MINI_SEP

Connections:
+3.3V: C1.1, C2.1, D1.2 (A), D2.2 (A), U1.14 (USB_VBUS), U1.44 (VDD_3V3), U1.45 (VDD_3V3), U1.54 (VANT); also elsewhere on the board
/mosaic-G5/ANT1: J1.1 (SIG), U1.2 (ANT_1)
D+: U1.12 (USB_DP); also elsewhere on the board
D-: U1.13 (USB_DN); also elsewhere on the board
LED1: U1.52 (GPIO1); also elsewhere on the board
unnamed: D1.1 (K), R1.2
unnamed: D2.1 (K), R4.2
unnamed: R1.1, U1.53 (GPIO2)
PPS_IN: U1.39 (EVENTA); also elsewhere on the board
PPS_OUT1: U1.42 (PPS1); also elsewhere on the board
PPS_OUT2: U1.43 (PPS2); also elsewhere on the board
REF_I: U1.48 (REF_I); also elsewhere on the board
REF_O: U1.47 (REF_O); also elsewhere on the board
UART_RX: U1.9 (RXD1); also elsewhere on the board
UART_TX: U1.10 (TXD1); also elsewhere on the board
VREF_I: U1.50 (VREF_I); also elsewhere on the board
VREF_O: U1.51 (VREF_O); also elsewhere on the board
~NRST_IN: U1.7 (NRST_IN); also elsewhere on the board

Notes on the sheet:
Mosaic-G5 T
Antenna
Power indicator LED
Schematics arranged by Laetitia.K

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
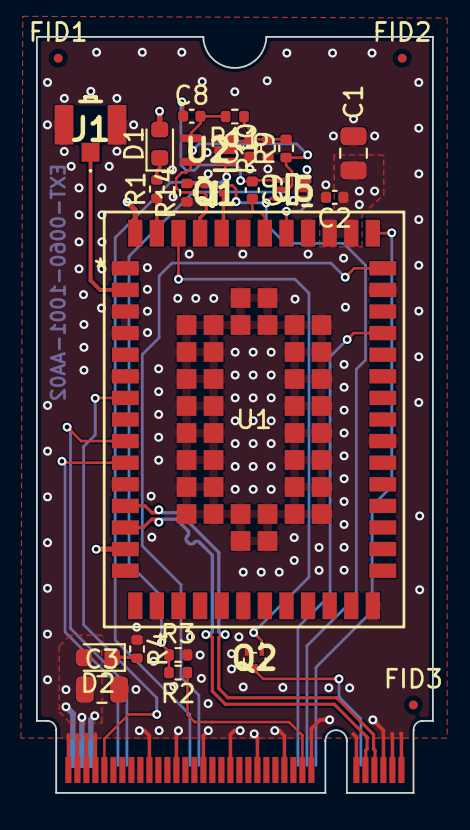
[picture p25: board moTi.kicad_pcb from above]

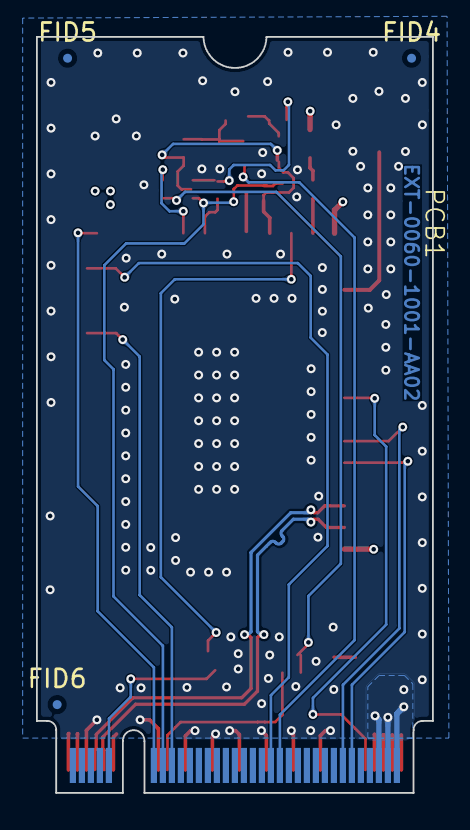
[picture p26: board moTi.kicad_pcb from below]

Board: 4 copper layers, 22.0 x 42.0 mm, 30 parts (4 on the bottom side), 27 nets.

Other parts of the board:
R14: 10k; R_0402_1005Metric

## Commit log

2026-03-04 KiCad folder
    [Clockdetect.kicad_sch, G5TimeSync.kicad_pcb, G5TimeSync.kicad_sch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]
2026-03-10 feedback update
    [G5Timesync BOM.csv]
2026-03-10 Update G5Timesync BOM.csv
    [G5Timesync BOM.csv]
2026-03-10 KiCad update
    [Clockdetect.kicad_sch, M2_Edge connector.kicad_sch, M2_PCB_OUTLINE.dxf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]
2026-03-15 HW files update
    [Clockdetect.kicad_sch, M2_Edge connector.kicad_sch, MosaicTimeSync.kicad_sch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]
2026-03-20 Septentrio logo
    [Clockdetect.kicad_sch, M2_Edge connector.kicad_sch, mosaic-G5.kicad_sch]
2026-03-20 schematic pdf
2026-03-22 update m.2 connector pic
2026-04-20 HW file update
    [Clockdetect.kicad_sch, G5Timesync BOM.csv, M2_Edge connector.kicad_sch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]
2026-05-26 I2C change
    [Clockdetect.kicad_sch, M2_Edge connector.kicad_sch, moTi.kicad_sch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]
2026-05-26 BOM update
    [Clockdetect.kicad_sch, M2_Edge connector.kicad_sch]
2026-05-26 schematic pdf update
2026-05-27 kicad file clean up
    [moTi.kicad_pcb]
2026-05-27 kicad clean up
    [M2_mosaicG5-B_Cu.gbl, M2_mosaicG5-B_Fab.gbr, M2_mosaicG5-B_Mask.gbs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]
2026-06-01 general clean up
    [Clockdetect.kicad_sch, M2_Edge connector.kicad_sch, moTi.kicad_pcb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]
2026-06-02 CAD file
    Plus documentation update
    [moTi.step]
2026-06-04 BOM
    xml files from library and BOM
    [moTi BOM.csv]
2026-06-04 Update .gitignore to remove BOM file exclusions
    Remove exported BOM file patterns from .gitignore
